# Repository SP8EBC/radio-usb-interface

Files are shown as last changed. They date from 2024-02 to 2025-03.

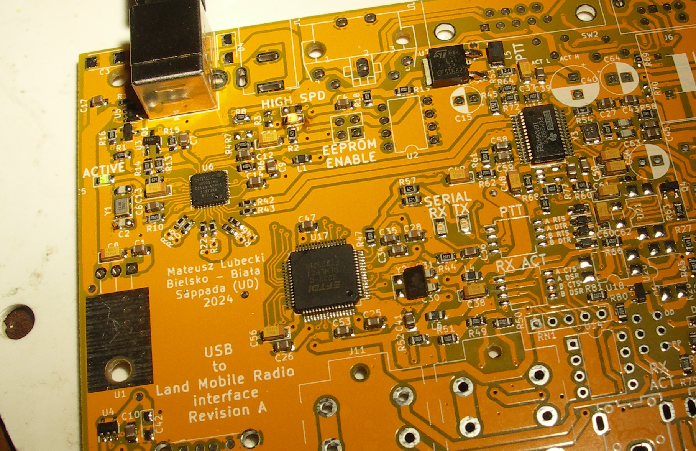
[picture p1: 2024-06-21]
_output_files/PICT0315.JPG

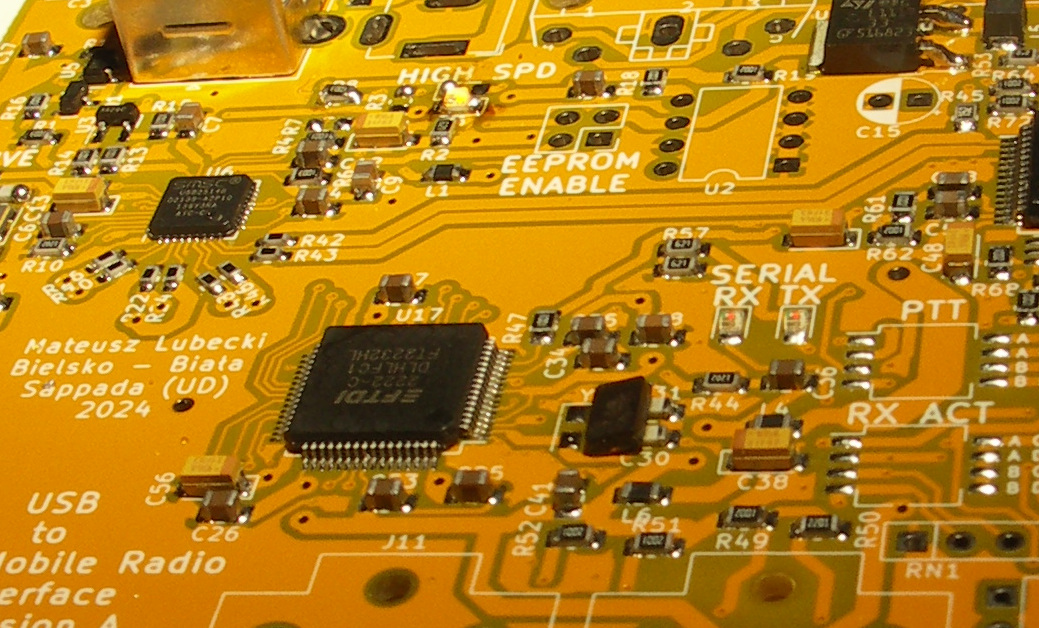
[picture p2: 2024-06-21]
_output_files/PICT0316.JPG

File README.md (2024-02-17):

# An USB interface between PC/RPi/ThinClient and any Land Mobile 2way Radio
Features:
1. Single USB connection to the PC.
2. Integrated USB 2.0 hub.
3. Integrated USB audio codec IC (Texas Instruments PCM2900) detected as a regular sound card.
4. Integrated double USB-UART controller (ftdi FT2232H) to control PTT and CarrierSense/COR/ChannelBusy lines.
5. Ground Separated RS232 for communication with the radio using CAT/IV-C or simmilar protocol
6. Ground Separated audio lines
7. Spare 2 USB ports exposed from the hub for connecting external devices.

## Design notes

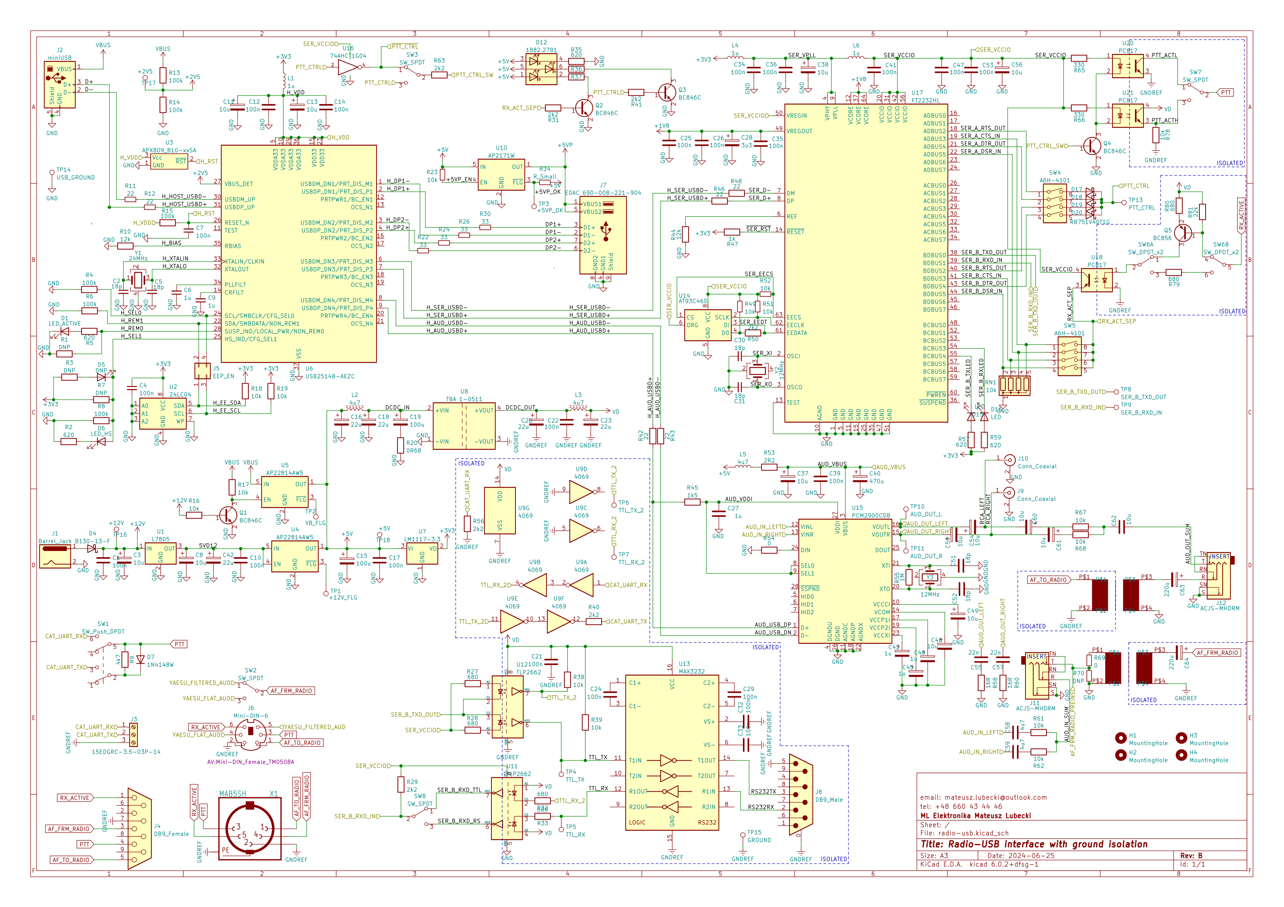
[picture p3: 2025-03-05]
__schematic/radio-usb.jpg

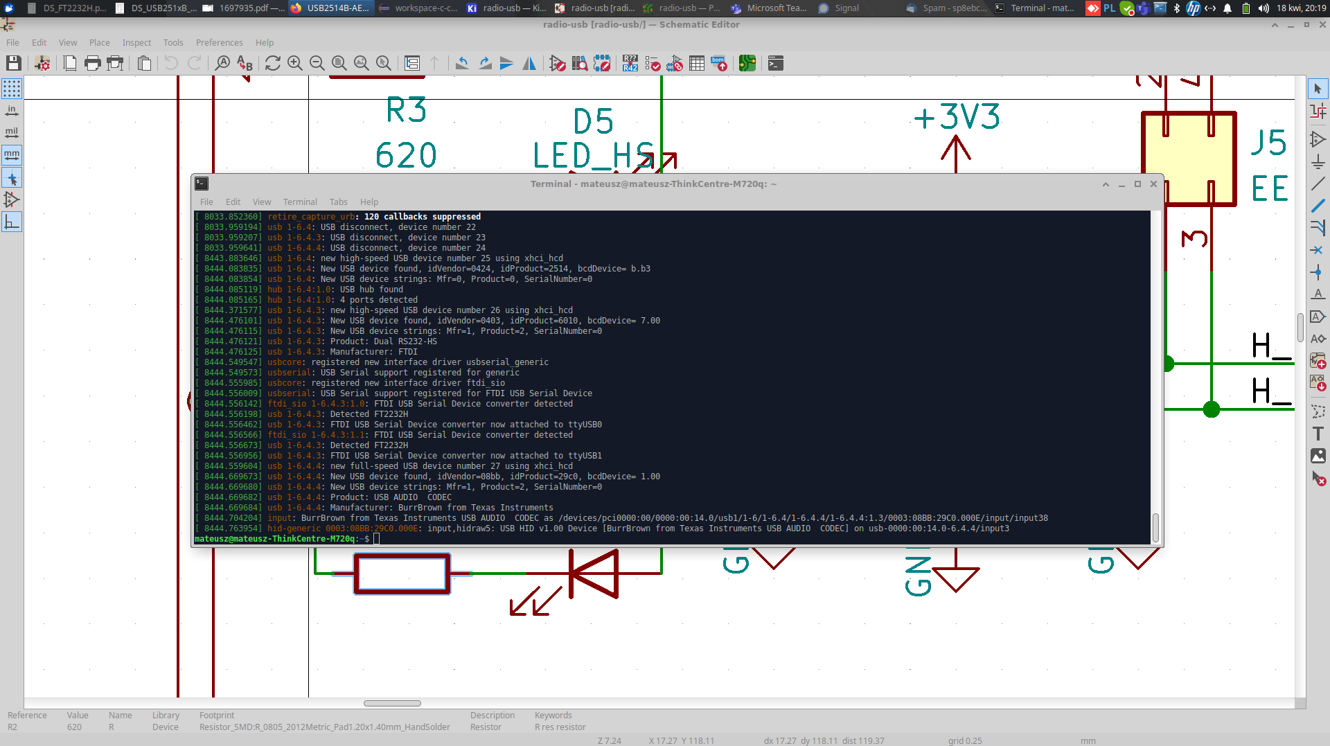
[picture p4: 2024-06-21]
_output_files/Screenshot_2024-04-18_20-19-46.png

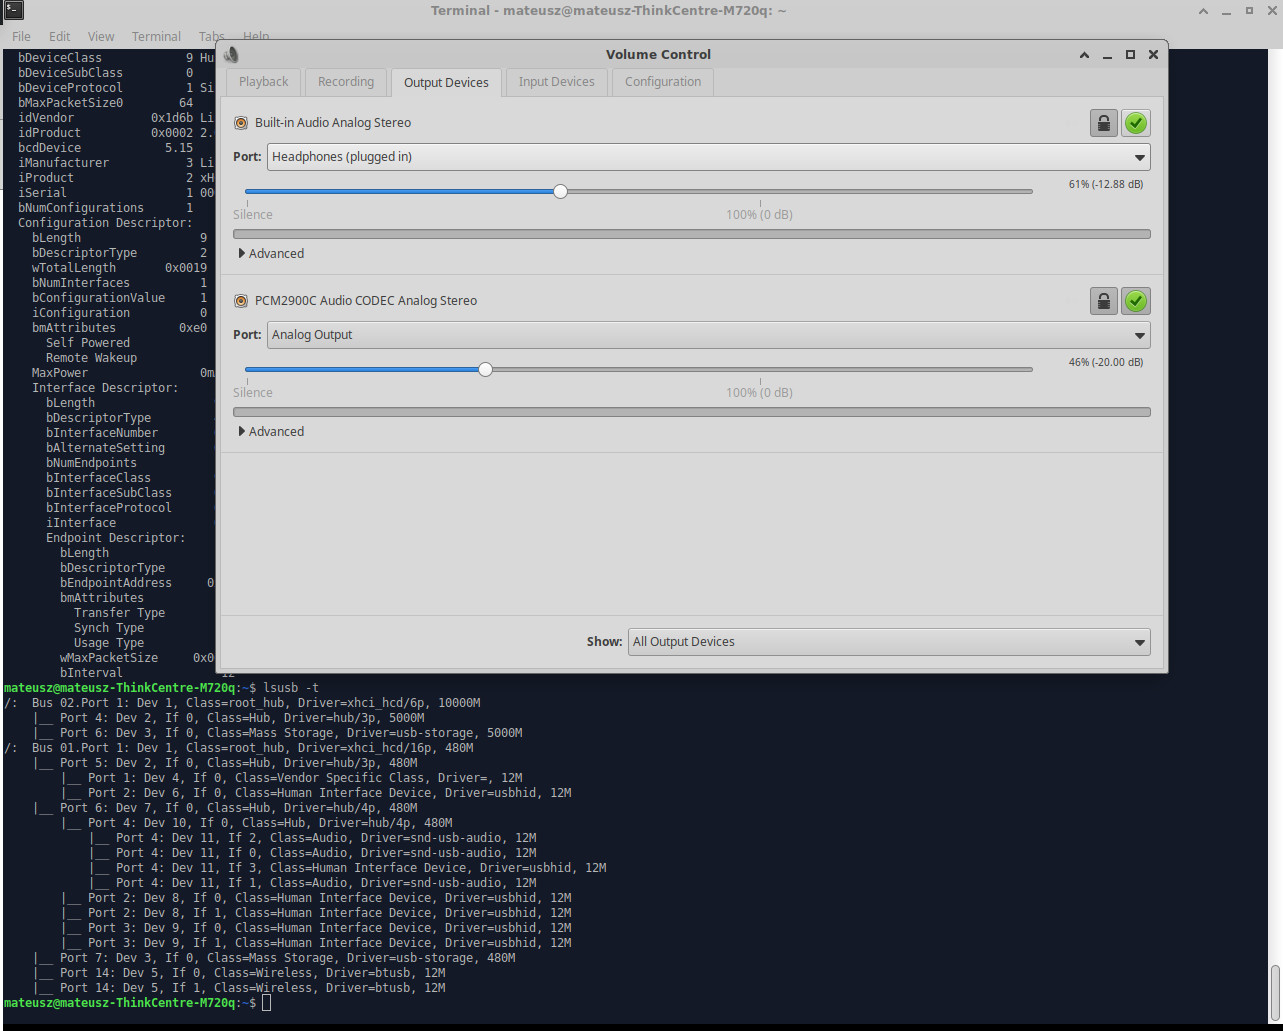
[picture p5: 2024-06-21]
_output_files/Screenshot_2024-04-16_18-32-28.jpg

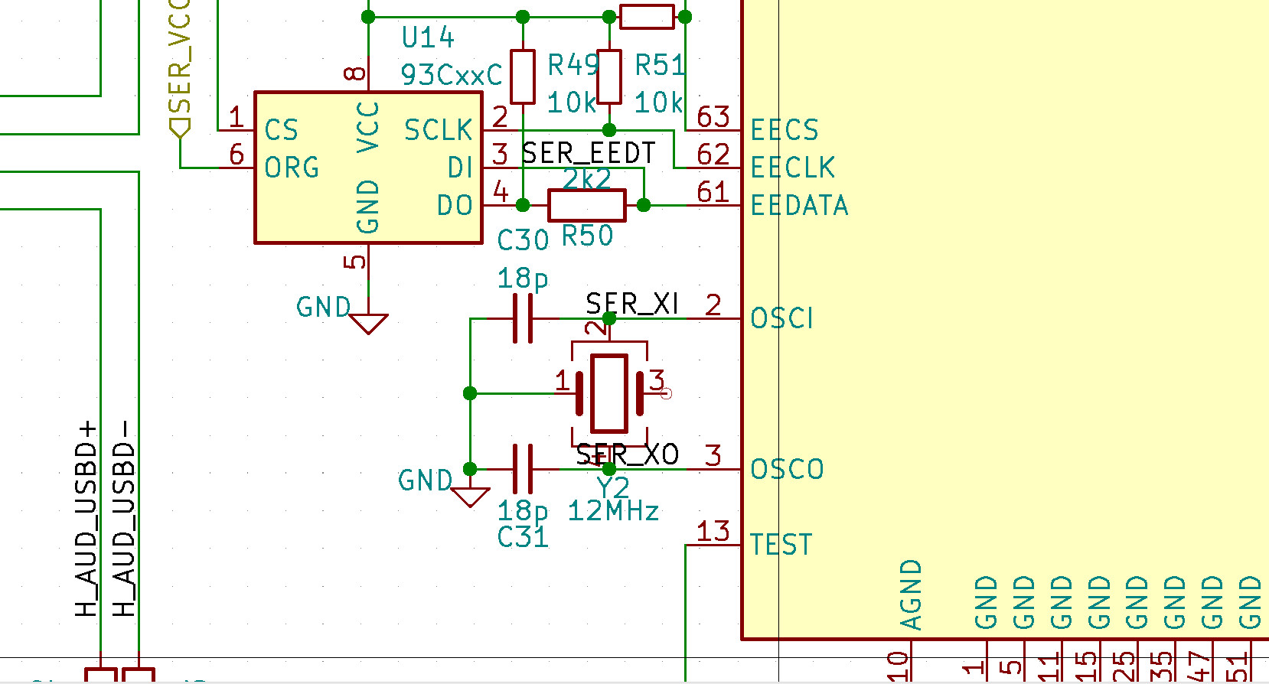
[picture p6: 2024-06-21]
_output_files/Screenshot_2024-04-16_21-14-47.jpg

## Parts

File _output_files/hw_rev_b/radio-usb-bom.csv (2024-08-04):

Reference | Quantity | Value | Footprint | Datasheet | DESCRIPTION
C1 C4 C7 C10 C12 C14 C17 C21 C22 C25 C26 C34 C35 C36 C39 C41 C47 C53 | 18 | 100n | Capacitor_SMD:C_0805_2012Metric_Pad1.18x1.45mm_HandSolder |  | 08051C104KAT2A KYOCERA AVX
C15 | 1 | 100u | Capacitor_THT:CP_Radial_D5.0mm_P2.50mm | https://www.tme.eu/Document/4bbe885c35326128adf3c0aebd83337c/e-bt.pdf | UBT1H101MPD8 NICHICON
C16 C18 C20 C23 C42 | 5 | 22u | Capacitor_Tantalum_SMD:CP_EIA-3216-18_Kemet-A_Pad1.58x1.35mm_HandSolder |  | TPSA106K010R0900 KYOCERA AVX
C19 | 1 | 100u | Capacitor_Tantalum_SMD:CP_EIA-3528-21_Kemet-B_Pad1.50x2.35mm_HandSolder |  | TPSA106K010R0900 KYOCERA AVX
C2 C5 C30 C31 C51 C52 | 6 | 18p | Capacitor_SMD:C_0805_2012Metric_Pad1.18x1.45mm_HandSolder |  | 08055A180JAT2A KYOCERA AVX
C24 C29 C32 C33 | 4 | 100n | Capacitor_SMD:C_0603_1608Metric_Pad1.08x0.95mm_HandSolder |  | 06033G104ZAT2A KYOCERA AVX
C28 | 1 | 3u3 | Capacitor_SMD:C_0805_2012Metric_Pad1.18x1.45mm_HandSolder |  | 0805ZD335KAT2A KYOCERA AVX
C3 | 1 | 10u | Capacitor_Tantalum_SMD:CP_EIA-6032-28_Kemet-C_Pad2.25x2.35mm_HandSolder |  | TPSA106K010R0900 KYOCERA AVX
C40 | 1 | 470u | Capacitor_THT:CP_Radial_D8.0mm_P3.50mm |  | NICHICON UHE1A471MPD1TA
C55 C57 | 2 | 22n | Capacitor_SMD:C_0805_2012Metric_Pad1.18x1.45mm_HandSolder |  | 08051C223KAT2A KYOCERA AVX
C58 C59 | 2 | 4u7 | Capacitor_SMD:C_0805_2012Metric_Pad1.18x1.45mm_HandSolder |  | 0805YC475KAT2A KYOCERA AVX
C6 C9 C27 C43 C45 C46 | 6 | 1u | Capacitor_SMD:C_0805_2012Metric_Pad1.18x1.45mm_HandSolder |  | 0805YC105KAT2A KYOCERA AVX
C62 | 1 | 10u | Capacitor_SMD:C_1206_3216Metric_Pad1.33x1.80mm_HandSolder |  | CL31A106MAHNNNE SAMSUNG
C63 C64 | 2 | 220u | Capacitor_THT:CP_Radial_D6.3mm_P2.50mm | https://www.tme.eu/Document/4bbe885c35326128adf3c0aebd83337c/e-bt.pdf | EEUFR1C221 PANASONIC
C8 C11 C13 C37 C38 C48 C49 C50 C54 C56 C60 C61 | 12 | 10u | Capacitor_Tantalum_SMD:CP_EIA-3216-18_Kemet-A_Pad1.58x1.35mm_HandSolder |  | TPSA106K010R0900 KYOCERA AVX
D1 | 1 | LED_ACTIVE | LED_SMD:LED_0805_2012Metric_Pad1.15x1.40mm_HandSolder |  | KPT-2012CGCK KINGBRIGHT ELECTRONIC
D12 | 1 | 1882.2781 | LED:LED_MENTOR_1882 | https://www.cree.com/led-components/media/documents/1397-QLS6BFKW.pdf | 1882.2781 MENTOR
D15 D16 | 2 | LED | LED_SMD:LED_0805_2012Metric_Pad1.15x1.40mm_HandSolder |  | KP-2012SYCK KINGBRIGHT ELECTRONIC
D17 D18 D19 D20 | 4 | RB751V40T1G | Diode_SMD:D_SOD-323_HandSoldering | https://www.tme.eu/Document/b77eb958f5d9ac56ef472a800d34775b/RB751V40T1.PDF | RB751V40T1G ONSEMI
D4 | 1 | B130-13-F | Diode_SMD:D_SMA |  | B130-13-F DIODES INCORPORATED
D5 D6 | 2 | LED_HS | LED_SMD:LED_0805_2012Metric_Pad1.15x1.40mm_HandSolder |  | KPT-2012SURC KINGBRIGHT ELECTRONIC
D7 | 1 | 1N4148W | Diode_SMD:D_SOD-123 | https://www.vishay.com/docs/85748/1n4148w.pdf | 1N4148W-AQ DIOTEC SEMICONDUCTOR
H1 H2 H3 H4 | 4 | MountingHole | MountingHole:MountingHole_3.2mm_M3
J1 | 1 | Barrel_Jack | Connector_BarrelJack:BarrelJack_GCT_DCJ200-10-A_Horizontal
J11 J12 | 2 | ACJS-MHDRM | AV:Jack_6.35mm_ACJS-MHDRM |  | ACJS-MHDRM AMPHENOL
J2 | 1 | miniUSB | Connector_USB:USB_B_Lumberg_2411_02_Horizontal | ~ | DS1099-WN0 CONNFLY
J3 | 1 | 15EDGRC-3.5-03P-14 | Connector_Phoenix_MC:PhoenixContact_MC_1,5_3-G-3.5_1x03_P3.50mm_Horizontal | https://www.tme.eu/Document/c7e2facf434c6541c93efde757aaf5e6/607.pdf
J4 | 1 | DB9_Female | Connector_Dsub:DSUB-9_Female_Horizontal_P2.77x2.84mm_EdgePinOffset4.94mm_Housed_MountingHolesOffset7.48mm | ~ | DE09-SN-24 ADAM TECH
J5 | 1 | EEP_EN | Connector_PinHeader_2.54mm:PinHeader_2x02_P2.54mm_Vertical
J6 | 1 | Mini-DIN-6 | AV:Mini-DIN_Female_TM0508A | http://service.powerdynamics.com/ec/Catalog17/Section%2011.pdf | 4850.2610 SCHURTER
J7 | 1 | EDAC 690-008-221-904 | Connector_USB:USB_A_Wuerth_61400826021_Horizontal_Stacked | https://www.tme.eu/Document/bc38f05e107515c145d033d39722883f/690-008-221-904.pdf | EDAC 690-008-221-904
J8 | 1 | DB9_Male | Connector_Dsub:DSUB-9_Male_Horizontal_P2.77x2.84mm_EdgePinOffset4.94mm_Housed_MountingHolesOffset7.48mm | ~ | DE09-PN-24 ADAM TECH
J9 J10 | 2 | Conn_Coaxial | AV:rca_cliff_F68371 | ~
L1 L4 L6 | 3 | 1u | Inductor_SMD:L_0805_2012Metric_Pad1.15x1.40mm_HandSolder |  | Viking NL05KTC1R0
L2 L3 L5 | 3 | 4u7 | Inductor_SMD:L_1210_3225Metric_Pad1.42x2.65mm_HandSolder | https://www.tme.eu/Document/11b7ed33a7ee93321756e8b8c8bd2191/VIKING-NLV.pdf | Viking NLV10MTC4R7
Q1 Q2 Q3 Q4 | 4 | BC846C | Package_TO_SOT_SMD:SOT-23 | https://assets.nexperia.com/documents/data-sheet/BC846_SER.pdf | BC846C-AQ DIOTEC SEMICONDUCTOR
Q5 | 1 | BC856 | Package_TO_SOT_SMD:SOT-23 | https://www.onsemi.com/pub/Collateral/BC860-D.pdf | BC856B-AQ DIOTEC SEMICONDUCTOR
R1 R4 R6 R8 R13 R14 R15 | 7 | 100k | Resistor_SMD:R_0805_2012Metric_Pad1.20x1.40mm_HandSolder |  | ERJ6ENF1002V PANASONIC
R10 R44 | 2 | 12k | Resistor_SMD:R_0805_2012Metric_Pad1.20x1.40mm_HandSolder |  | ERJ6ENF1202V PANASONIC
R11 R12 R42 R43 R46 R48 | 6 | 22 | Resistor_SMD:R_0603_1608Metric_Pad0.98x0.95mm_HandSolder |  | ERJ3EKF22R0V PANASONIC
R17 R78 | 2 | 10k | Resistor_SMD:R_0603_1608Metric_Pad0.98x0.95mm_HandSolder |  | ERJ3EKF1002V PANASONIC
R2 R3 R5 R57 R59 | 5 | 620 | Resistor_SMD:R_0805_2012Metric_Pad1.20x1.40mm_HandSolder |  | ERJ6GEYJ621V PANASONIC
R20 | 1 | 0R68 | Resistor_SMD:R_1206_3216Metric_Pad1.30x1.75mm_HandSolder
R22 R24 R26 R30 | 4 | 33 | Resistor_SMD:R_0603_1608Metric_Pad0.98x0.95mm_HandSolder |  | ERJ3EKF33R0V PANASONIC
R27 R28 R32 R33 R79 R80 | 6 | 680 | Resistor_SMD:R_0805_2012Metric_Pad1.20x1.40mm_HandSolder |  | ERA6AEB681V PANASONIC
R29 R31 R40 R41 R50 R56 R63 | 7 | 2k2 | Resistor_SMD:R_0805_2012Metric_Pad1.20x1.40mm_HandSolder |  | ERJ6ENF2201V PANASONIC
R34 | 1 | R_Small | Resistor_SMD:R_0805_2012Metric_Pad1.20x1.40mm_HandSolder
R35 R36 R37 | 3 | 620 | Resistor_SMD:R_0603_1608Metric_Pad0.98x0.95mm_HandSolder |  | ERJ3EKF6200V PANASONIC
R45 | 1 | 1k5 | Resistor_SMD:R_0805_2012Metric_Pad1.20x1.40mm_HandSolder |  | ERA6AEB152V PANASONIC
R47 | 1 | 1k | Resistor_SMD:R_0805_2012Metric_Pad1.20x1.40mm_HandSolder |  | ERJ6ENF1001V PANASONIC
R53 | 1 | 2R2 | Resistor_SMD:R_0805_2012Metric_Pad1.20x1.40mm_HandSolder |  | ERJP06J2R2V PANASONIC
R54 | 1 | 0 | Resistor_SMD:R_0805_2012Metric_Pad1.20x1.40mm_HandSolder |  | ERJ6GEY0R00V PANASONIC
R55 | 1 | 1M | Resistor_SMD:R_0805_2012Metric_Pad1.20x1.40mm_HandSolder |  | ERJ6ENF1004V PANASONIC
R58 R60 | 2 | 16R | Resistor_SMD:R_0805_2012Metric_Pad1.20x1.40mm_HandSolder |  | 0805S8F160JT5E ROYAL OHM
R65 R66 | 2 | 330 | Resistor_SMD:R_0805_2012Metric_Pad1.20x1.40mm_HandSolder |  | ERJ6ENF3300V PANASONIC
R69 | 1 | 0 | Resistor_SMD:R_0603_1608Metric_Pad0.98x0.95mm_HandSolder |  | ERJ3GEY0R00V PANASONIC
R7 R16 R18 R19 R23 R38 R39 R49 R51 R52 R61 R62 R67 R68 | 14 | 10k | Resistor_SMD:R_0805_2012Metric_Pad1.20x1.40mm_HandSolder |  | ERJ6ENF1002V PANASONIC
R70 | 1 | DNP | Resistor_SMD:R_0603_1608Metric_Pad0.98x0.95mm_HandSolder
R81 | 1 | 22k | Resistor_SMD:R_0805_2012Metric_Pad1.20x1.40mm_HandSolder |  | ERJ6ENF2202V PANASONIC
R9 | 1 | 4k7 | Resistor_SMD:R_0805_2012Metric_Pad1.20x1.40mm_HandSolder |  | ERJ6ENF4701V PANASONIC
RN1 | 1 | 10k | Resistor_THT:R_Array_SIP5 | http://www.vishay.com/docs/31509/csc.pdf | RNLA05G0103B0E ROYAL OHM
SW1 | 1 | SW_Push_DPDT | switches_spdt_dpdt:Alps_SSSS222700 | https://www.tme.eu/Document/c62ad11cd91cb94020bc0a3c66211e45/SSSS222700.PDF | Alps SSSS222700
SW2 SW7 | 2 | SW_SPDT | switches_spdt_dpdt:Alps_SSSS213000 | https://www.tme.eu/Document/2a8ee3f094bc2d9567cff99b6818da87/SSSS213000.PDF | SSSS213000 ALPS
SW3 | 1 | SW_SPDT | switches_spdt_dpdt:TL3XWO
SW4 SW5 | 2 | A6H-4101 | Button_Switch_SMD:SW_DIP_SPSTx04_Slide_Copal_CHS-04B_W7.62mm_P1.27mm |  | OMRON A6H-4101
SW6 | 1 | SW_DPDT_x2 | switches_spdt_dpdt:Alps_SSSS222700 | https://www.tme.eu/Document/c62ad11cd91cb94020bc0a3c66211e45/SSSS222700.PDF | ALPS SSSS222700
SW8 | 1 | SW_SPDT | switches_spdt_dpdt:Ninigi_MSS-2235S | https://www.tme.eu/Document/2a8ee3f094bc2d9567cff99b6818da87/SSSS213000.PDF | SSSS213000 ALPS
TP1 | 1 | +12V_FLG | TestPoint:TestPoint_Pad_D1.0mm
TP10 | 1 | AUD_OUT_L | TestPoint:TestPoint_Pad_D2.0mm
TP11 | 1 | AUD_OUT_R | TestPoint:TestPoint_Pad_D2.0mm
TP13 | 1 | PTT_CTRL | TestPoint:TestPoint_Pad_D2.0mm
TP14 | 1 | USB_GROUND | TestPoint:TestPoint_Pad_D2.0mm
TP15 | 1 | GROUND | TestPoint:TestPoint_Pad_D2.0mm
TP16 | 1 | +12V | TestPoint:TestPoint_Pad_D2.0mm
TP17 | 1 | +2V5 | TestPoint:TestPoint_Pad_D2.0mm
TP18 | 1 | +5V | TestPoint:TestPoint_Pad_D2.0mm
TP2 | 1 | VB_FLG | TestPoint:TestPoint_Pad_D1.0mm
TP3 | 1 | +5VP_OK | TestPoint:TestPoint_Pad_D2.0mm
TP4 | 1 | TTL_TX | TestPoint:TestPoint_Pad_D1.0mm
TP5 | 1 | TTL_RX | TestPoint:TestPoint_Pad_D1.0mm
TP6 | 1 | TTL_TX_2 | TestPoint:TestPoint_Pad_D1.0mm
TP7 | 1 | TTL_RX_2 | TestPoint:TestPoint_Pad_D2.0mm
TP8 | 1 | SER_B_TXD_OUT | TestPoint:TestPoint_Pad_D2.0mm
TP9 | 1 | SER_B_RXD_IN | TestPoint:TestPoint_Pad_D1.0mm
U1 | 1 | L7805 | Package_TO_SOT_THT:TO-220-3_Horizontal_TabDown | http://www.st.com/content/ccc/resource/technical/document/datasheet/41/4f/b3/b0/12/d4/47/88/CD00000444.pdf/files/CD00000444.pdf/jcr:content/translations/en.CD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
U10 | 1 | AP2171W | Package_TO_SOT_SMD:SOT-23-5 | https://www.diodes.com/assets/Datasheets/AP2161.pdf | DIODES INCORPORATED AP2171WG-7
U13 | 1 | MAX3232 | Package_SO:TSSOP-16_4.4x5mm_P0.65mm | https://datasheets.maximintegrated.com/en/ds/MAX3222-MAX3241.pdf
U14 | 1 | AT93C46D | Package_DIP:DIP-8_W7.62mm | http://ww1.microchip.com/downloads/en/DeviceDoc/20001749K.pdf | 93C46A-I/P MICROCHIP TECHNOLOGY
U15 | 1 | PCM2900CDB | Package_SO:SSOP-28_5.3x10.2mm_P0.65mm | http://www.ti.com/lit/ds/symlink/pcm2902c.pdf | TEXAS INSTRUMENTS PCM2900CDB
U16 | 1 | 74AHCT1G04 | Package_TO_SOT_SMD:SOT-23-5_HandSoldering | http://www.ti.com/lit/sg/scyt129e/scyt129e.pdf
U17 | 1 | FT2232HL | Package_QFP:LQFP-64_10x10mm_P0.5mm | https://www.ftdichip.com/Support/Documents/DataSheets/ICs/DS_FT2232H.pdf | FTDI FT2232HL
U18 U20 U21 | 3 | PC817 | Package_DIP:SMDIP-4_W7.62mm | http://www.soselectronic.cz/a_info/resource/d/pc817.pdf
U19 U22 | 2 | CRIYCHLEY9000 | paratnc_cp:NORMAL
U2 | 1 | 24LC04 | Package_DIP:DIP-8_W7.62mm | http://ww1.microchip.com/downloads/en/DeviceDoc/21708K.pdf | 24LC04BH-I/P MICROCHIP TECHNOLOGY
U3 | 1 | APX809_810-xxSA | Package_TO_SOT_SMD:SOT-23_Handsoldering |  | APX809S-29SA-7 DIODES INCORPORATED
U4 U5 | 2 | AP22814AW5 | Package_TO_SOT_SMD:SOT-23-5 | https://www.diodes.com/assets/Datasheets/AP22804_14.pdf | DIODES INCORPORATED AP22814AW5-7
U6 | 1 | USB2514B-AEZC | Package_DFN_QFN:QFN-36-1EP_6x6mm_P0.5mm_EP3.7x3.7mm | http://ww1.microchip.com/downloads/en/DeviceDoc/00001692C.pdf | MICROCHIP TECHNOLOGY USB2514B-AEZC
U7 | 1 | LM1117-3.3 | Package_TO_SOT_SMD:TO-252-2 | http://www.ti.com/lit/ds/symlink/lm1117.pdf | LM1117DTX-3.3 TEXAS INSTRUMENTS
U8 | 1 | TBA 1-0511 | Converter_DCDC:Converter_DCDC_Murata_CRE1xxxxxx3C_THT | https://www.tme.eu/Document/04c8092078f15ad8e8fca758a461a5e9/tba1-datasheet.pdf | TBA 1-0511 TRACO POWER
U9 | 1 | 4069 | Package_SO:TSSOP-14_4.4x5mm_P0.65mm | http://www.intersil.com/content/dam/Intersil/documents/cd40/cd4069ubms.pdf
X1 | 1 | MAB5SH | sterownik-eagle:MAB5SH
Y1 | 1 | 24MHz | Crystal:Crystal_SMD_Abracon_ABM8G-4Pin_3.2x2.5mm |  | 24.00M-SMDXT324 YIC
Y2 Y3 | 2 | 12MHz | Crystal:Crystal_SMD_Abracon_ABM8G-4Pin_3.2x2.5mm |  | 7V-12.000MDDJ-T TXC

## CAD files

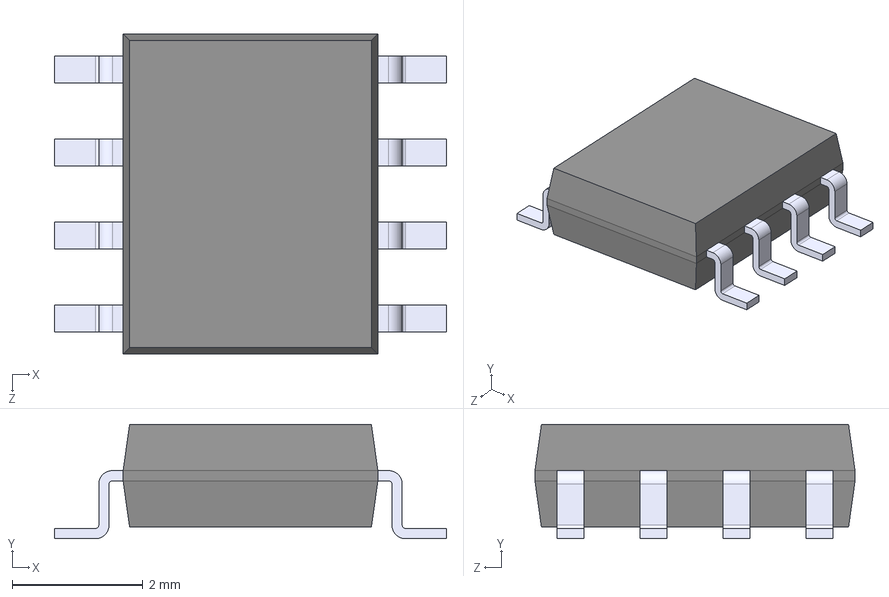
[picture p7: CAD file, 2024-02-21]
MIC5209-3.6YM/MIC5209-3.6YM.step
6.00 x 1.75 x 4.90 mm

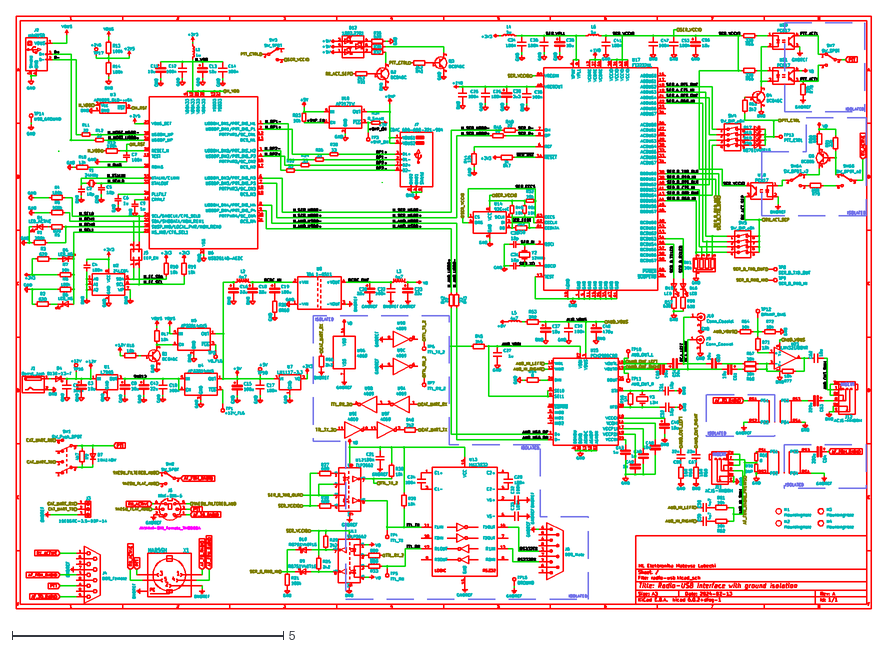
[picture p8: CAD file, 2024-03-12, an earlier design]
_output_files/hw_rev_a/___schematic/radio-usb.dxf
15.7 x 10.9

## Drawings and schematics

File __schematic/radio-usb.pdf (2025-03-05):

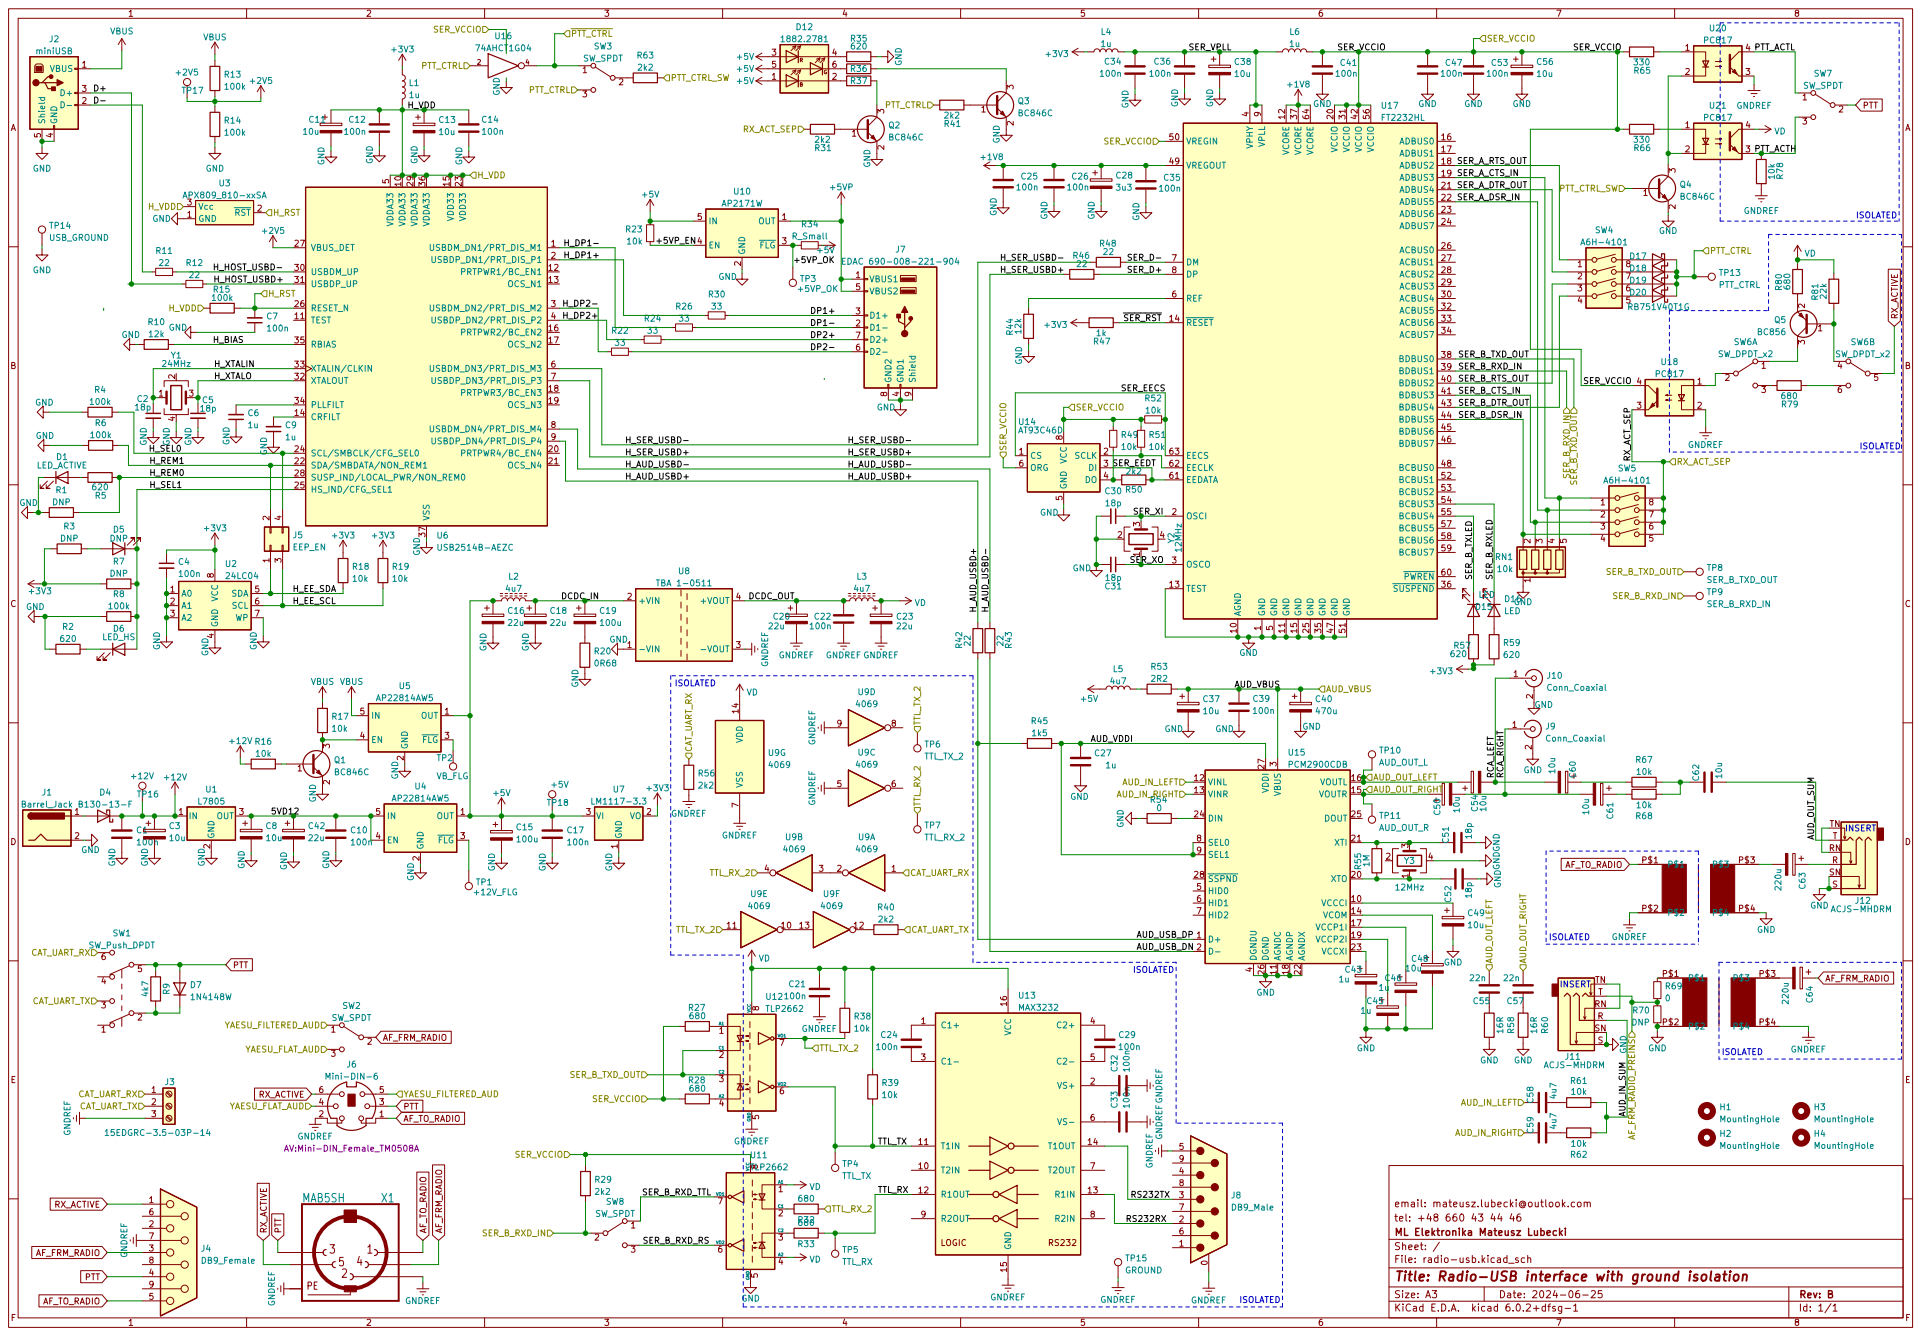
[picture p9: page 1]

1 AGND 10 GND 11 VCORE 12 TEST 13 ~{RESET} 14 GND 15 ADBUS0 16 ADBUS1 17 ADBUS2 18 ADBUS3 19 OSCI 2 VCCIO 20 ADBUS4 21 ADBUS5 22 ADBUS6 23 ADBUS7 24 GND 25 ACBUS0 26 ACBUS1 27 ACBUS2 28 ACBUS3 29 OSCO 3 ACBUS4 30 VCCIO 31 ACBUS5 32 ACBUS6 33 ACBUS7 34 GND 35

4 BDBUS2 40 BDBUS3 41 VCCIO 42 BDBUS4 43 BDBUS5 44 BDBUS6 45 BDBUS7 46 GND 47 BCBUS0 48 VREGOUT 49 GND

5 VREGIN 50 GND 51 BCBUS1 52 BCBUS2 53 BCBUS3 54 BCBUS4 55 VCCIO 56 BCBUS5 57 BCBUS6 58 BCBUS7 59 REF 6 ~{PWREN} 60 EEDATA 61 EECLK 62 EECS 63 VCORE 64 DM 7 DP 8 VPLL

4 SDA 5 SCL 6 WP 7 VCC

J6 Mini-DIN-6 AV:Mini-DIN_Female_TM0508A

email: mateusz.lubecki@outlook.com
tel: +48 660 43 44 46
File: radio-usb.kicad_sch Sheet: / ML Elektronika Mateusz Lubecki

Id: 1/1 Title: Radio-USB interface with ground isolation

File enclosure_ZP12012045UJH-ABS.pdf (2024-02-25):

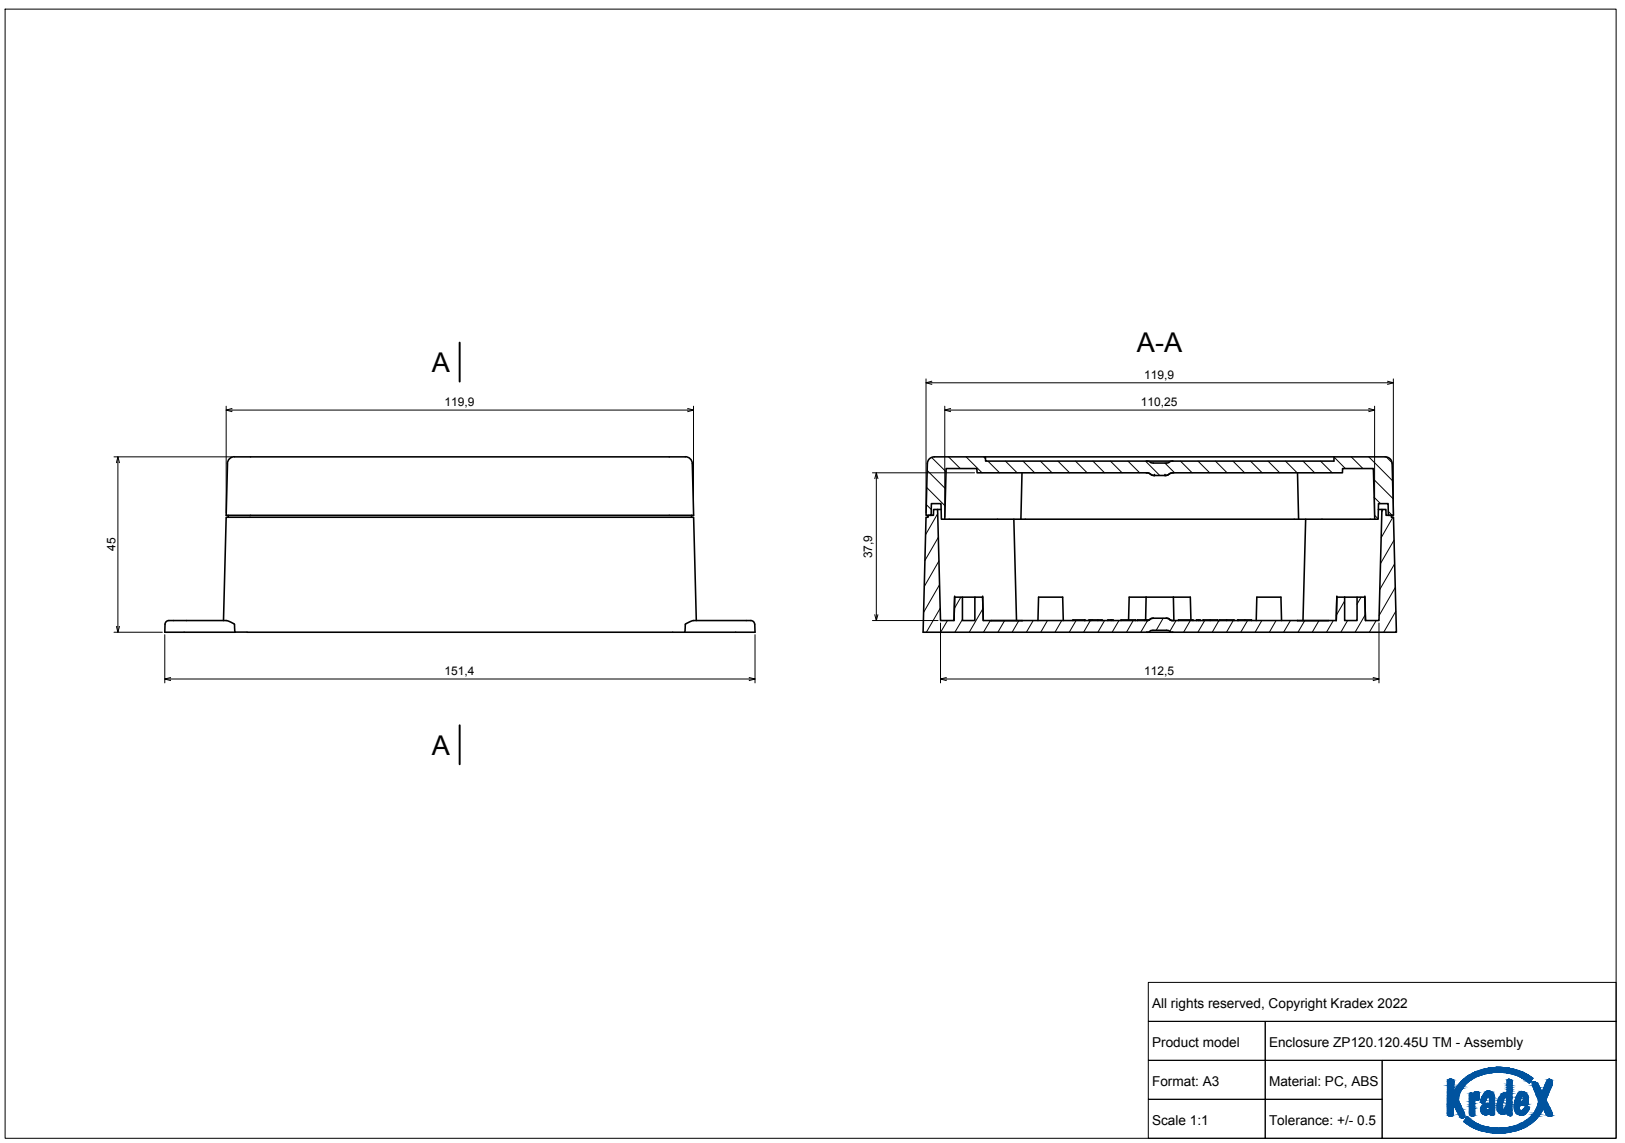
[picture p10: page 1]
Product model Format: A3 Scale 1:1; Tolerance: +/- 0.5 Material: PC, ABS Enclosure ZP120.120.45U TM - Assembly All rights reserved, Copyright Kradex 2022 AA

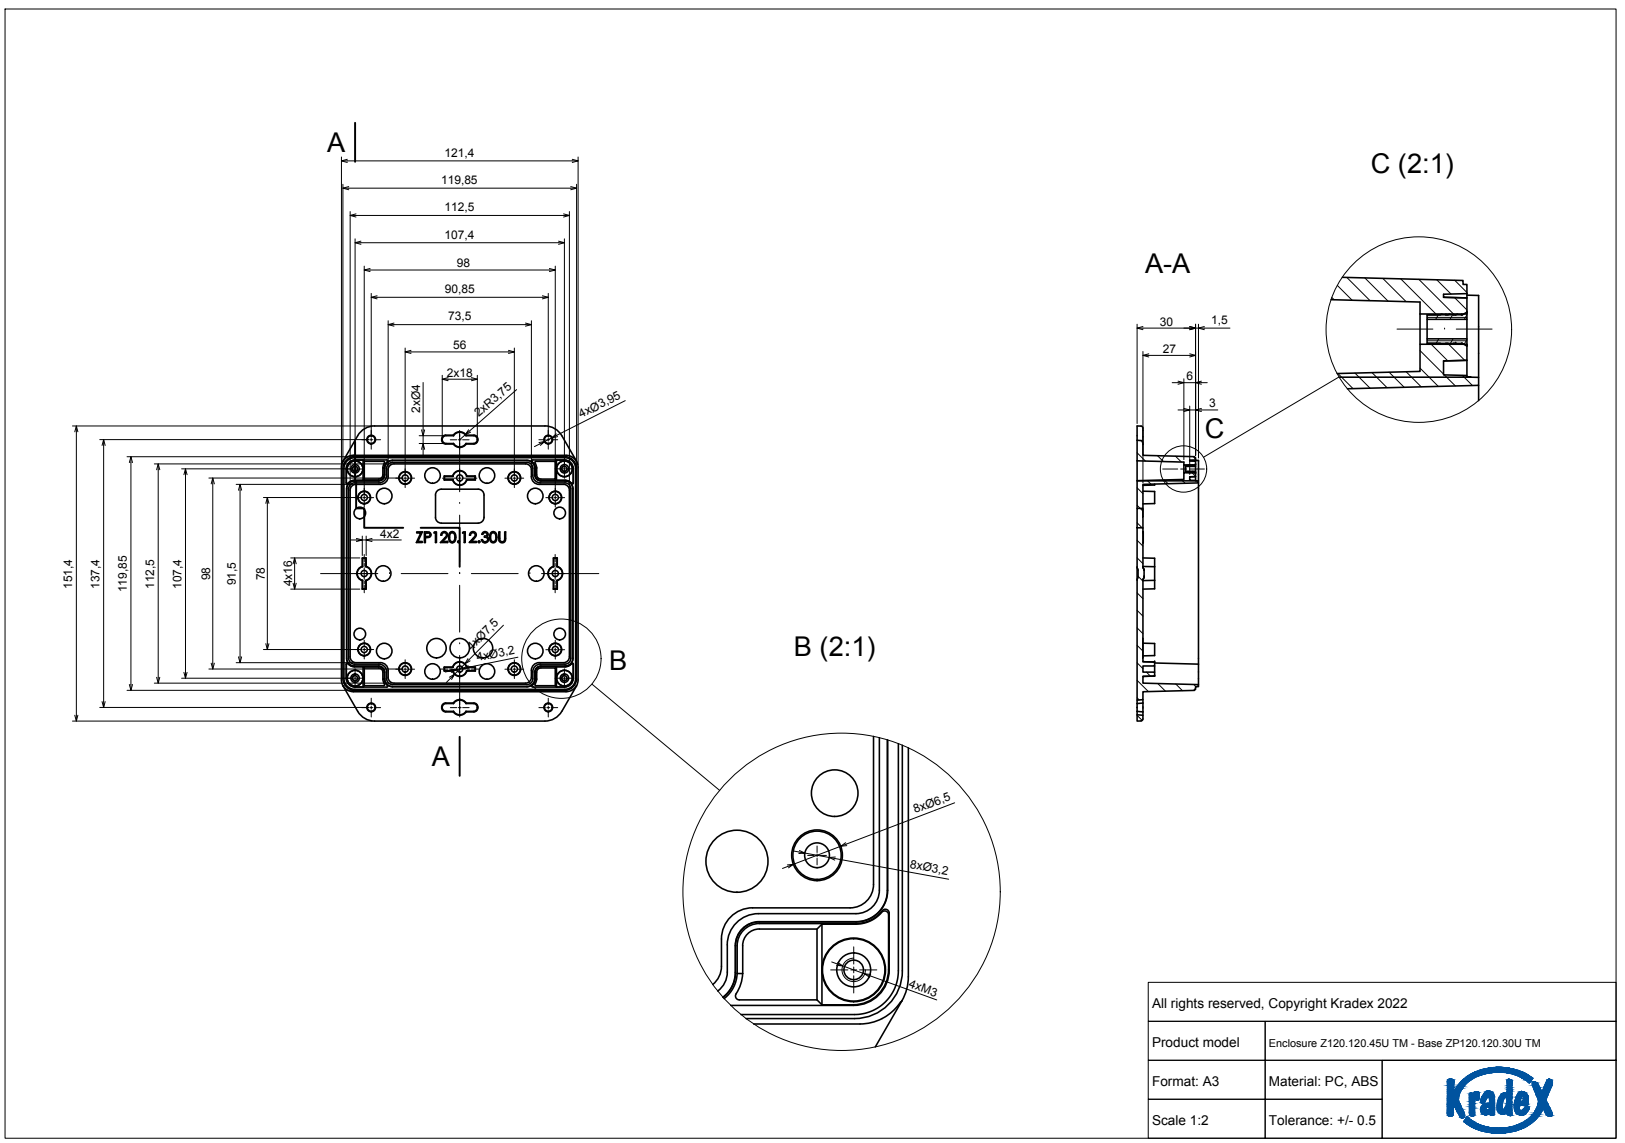
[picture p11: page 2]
Product model Format: A3 Scale 1:2; Tolerance: +/- 0.5 Material: PC, ABS Enclosure Z120.120.45U TM - Base ZP120.120.30U TM All rights reserved, Copyright Kradex 2022 A

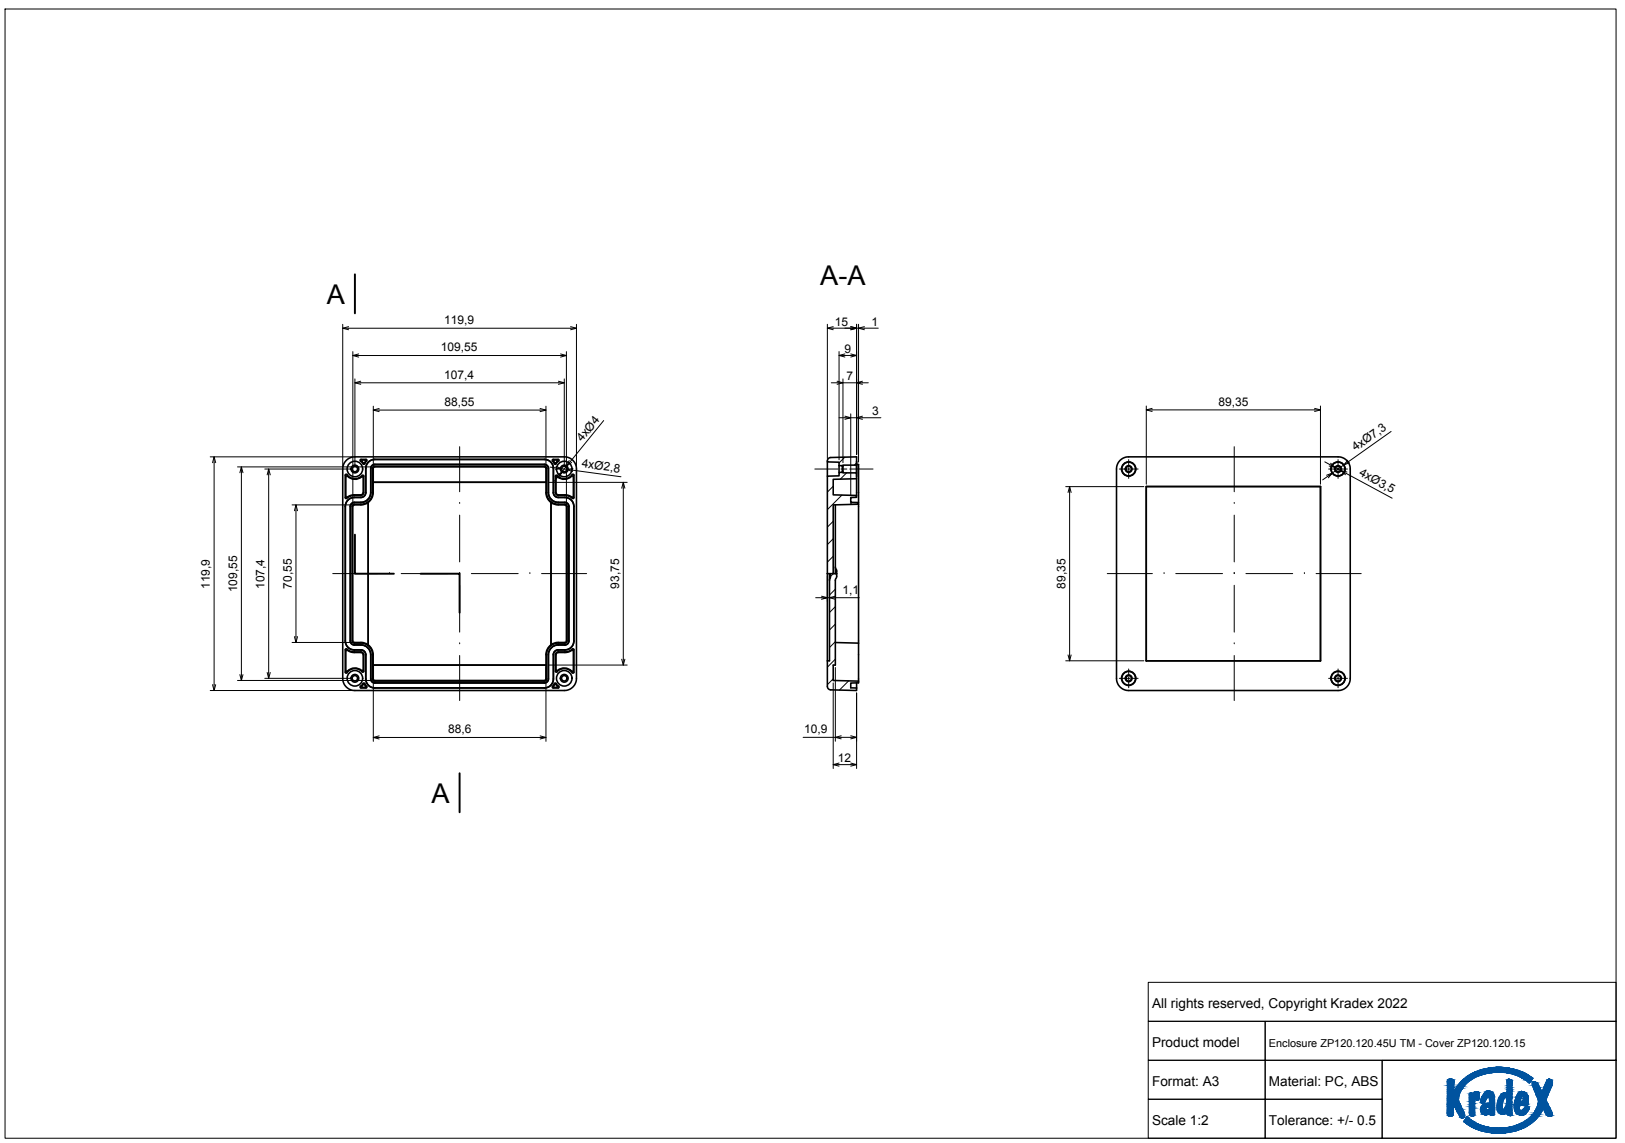
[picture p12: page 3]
Product model Format: A3 Scale 1:2; Tolerance: +/- 0.5 Material: PC, ABS Enclosure ZP120.120.45U TM - Cover ZP120.120.15 All rights reserved, Copyright Kradex 2022

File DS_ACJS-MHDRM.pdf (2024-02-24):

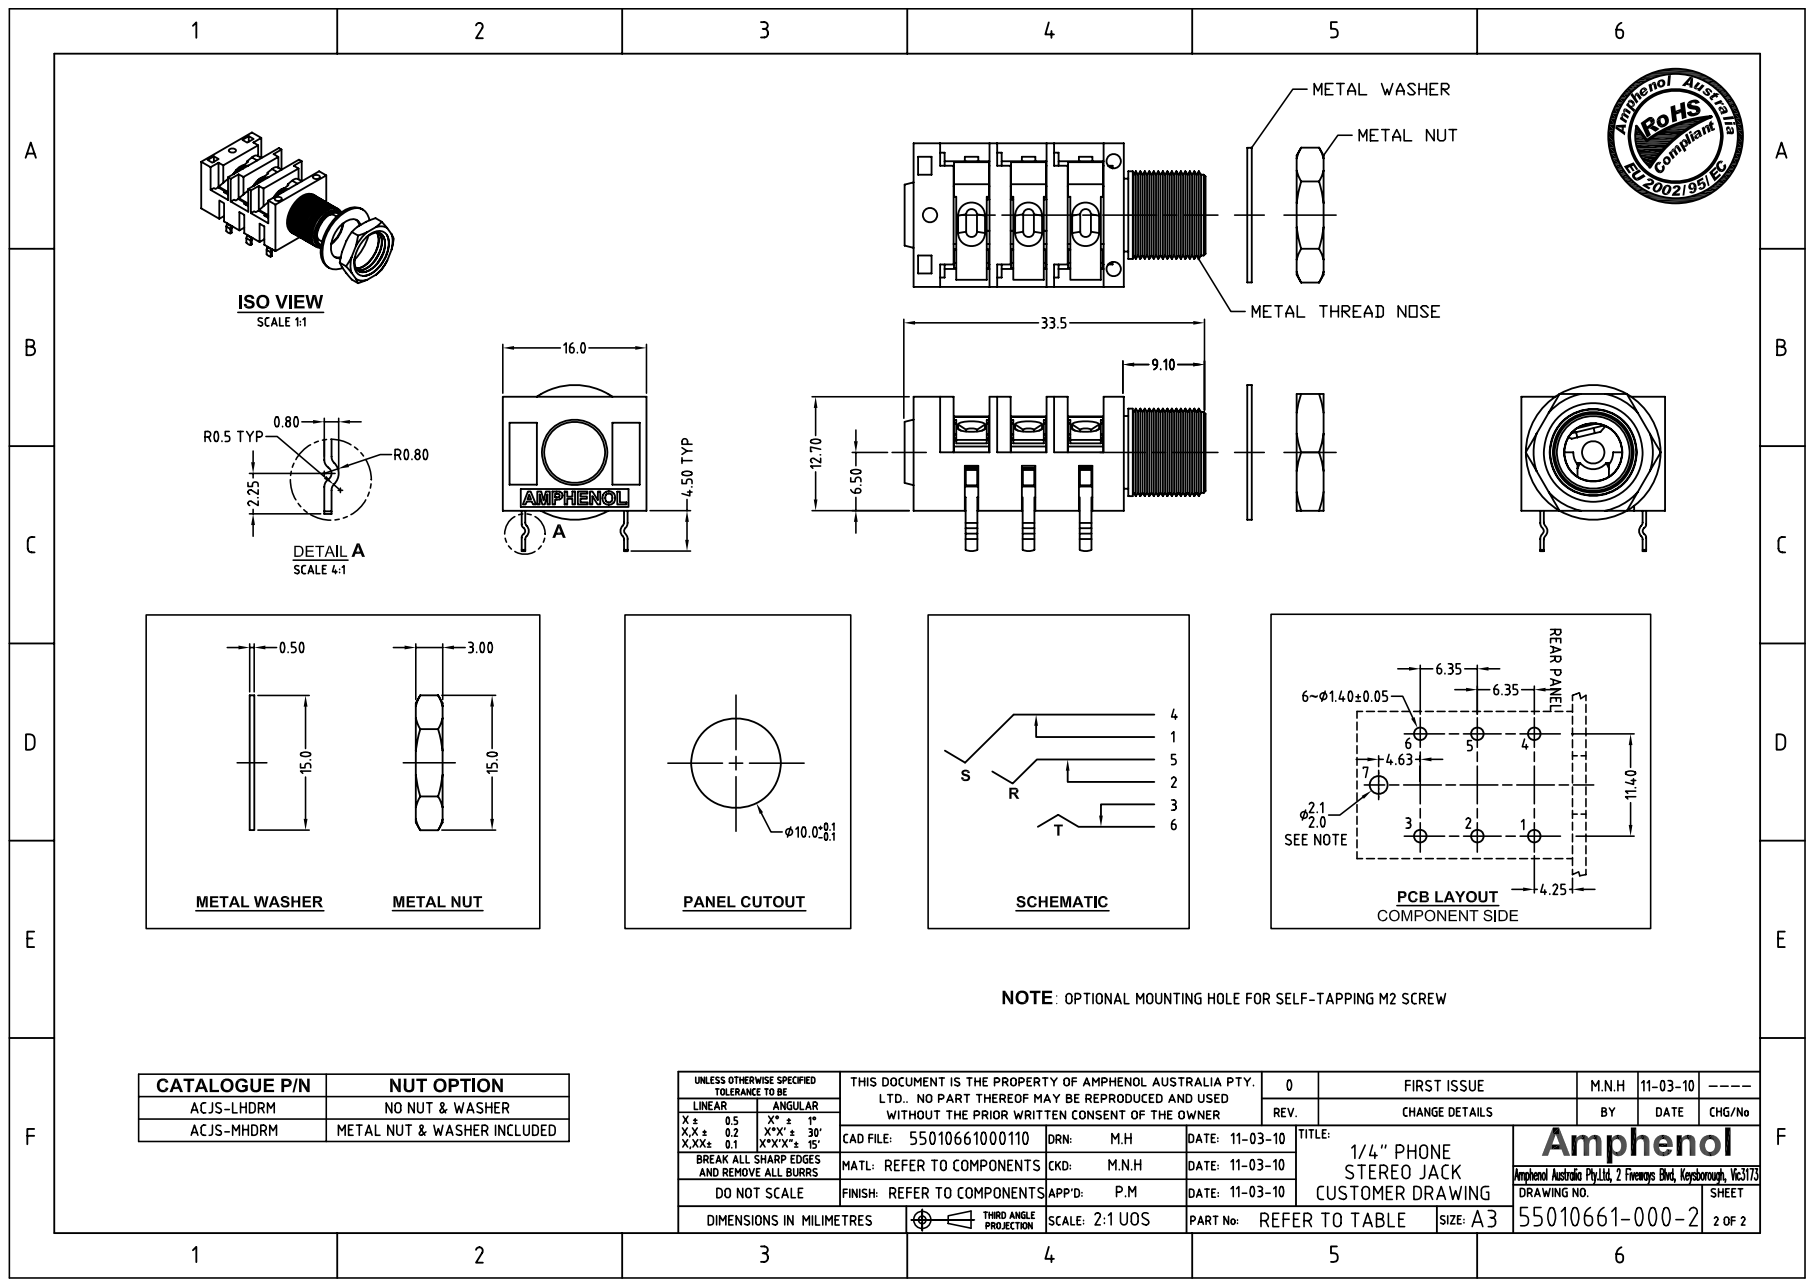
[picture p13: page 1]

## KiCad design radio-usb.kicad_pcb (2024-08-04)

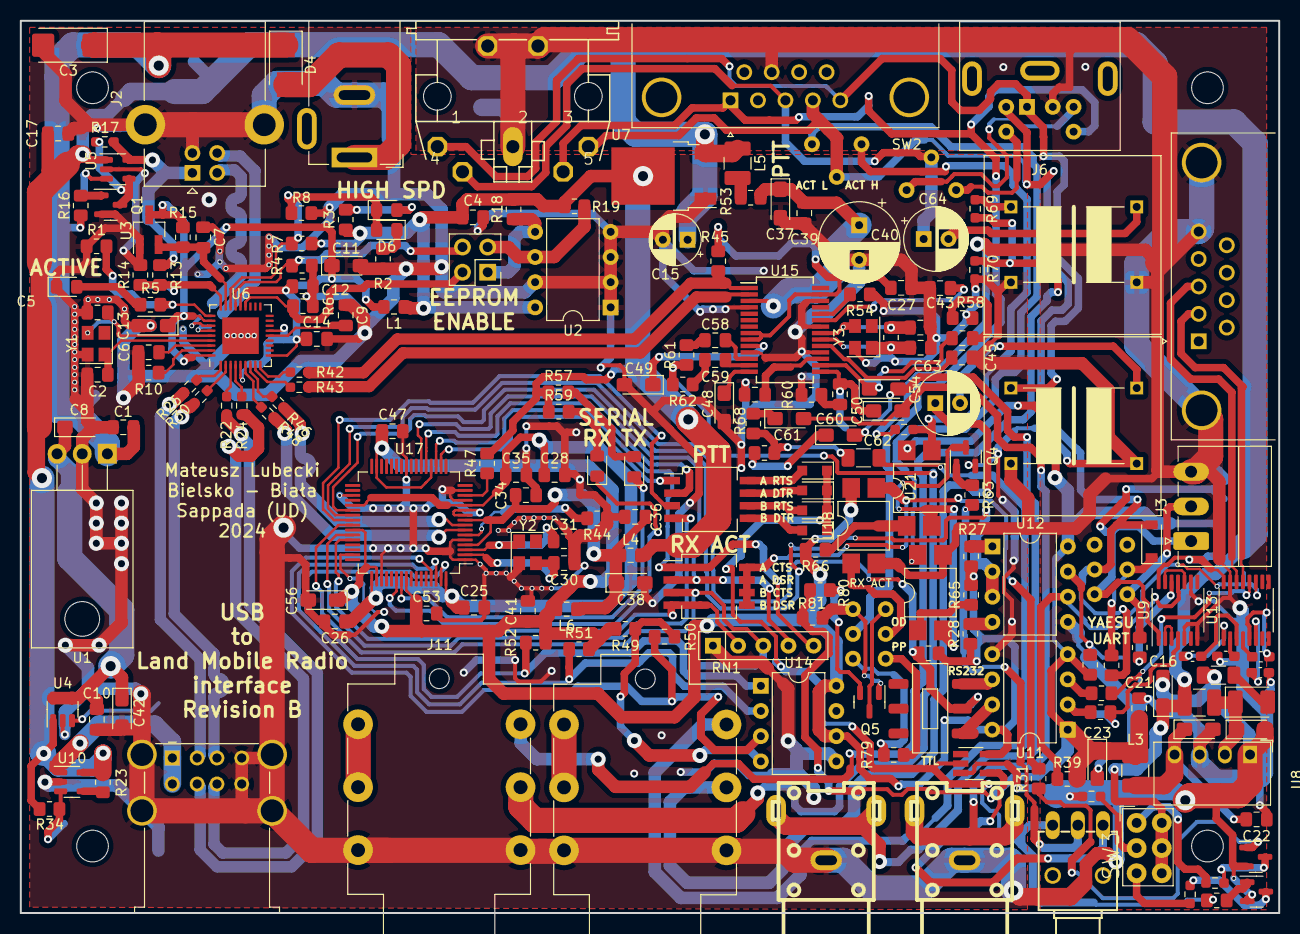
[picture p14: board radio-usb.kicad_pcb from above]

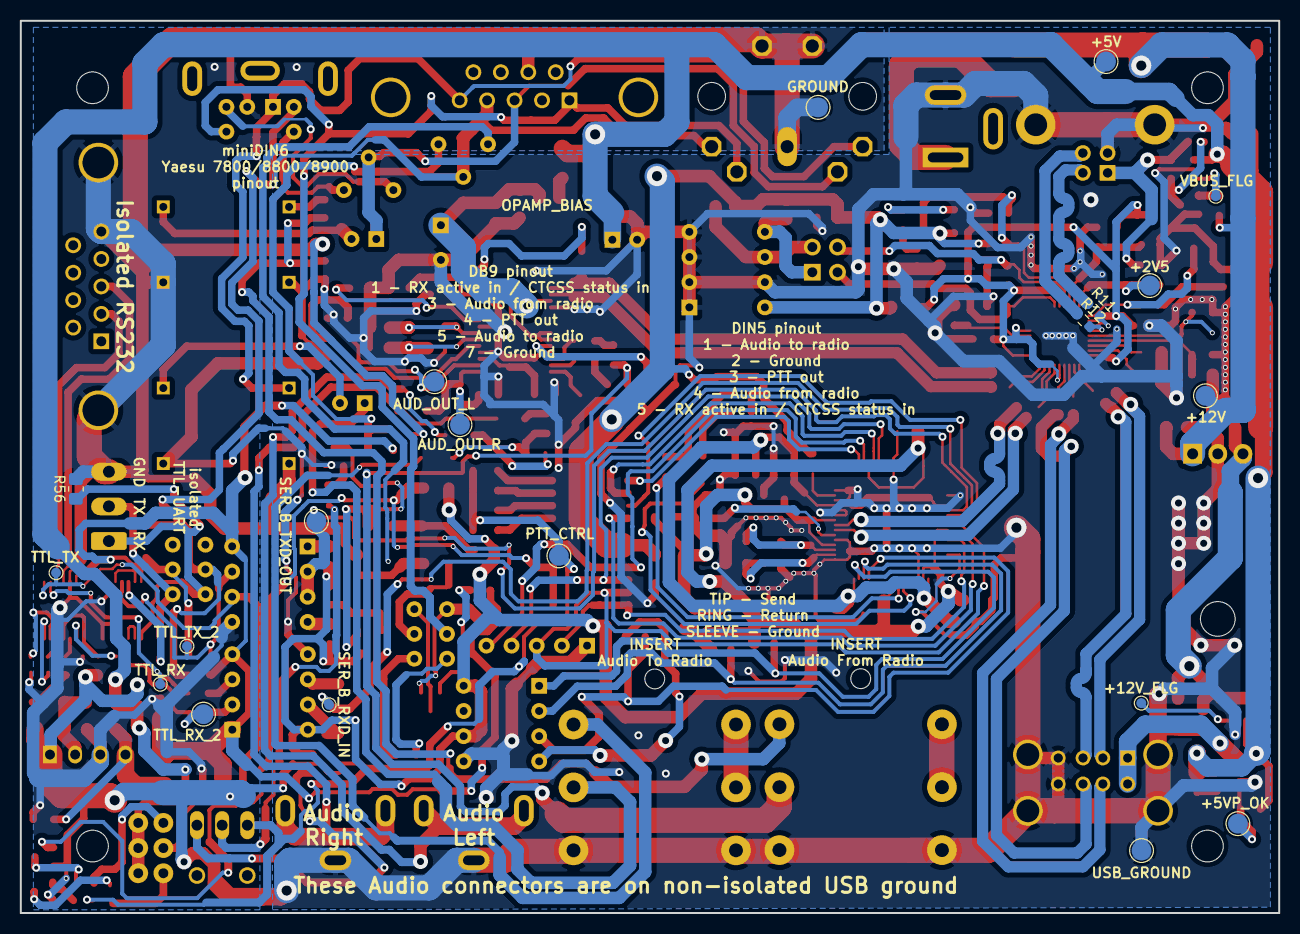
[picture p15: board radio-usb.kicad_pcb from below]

Board: 2 copper layers, 127.0 x 90.0 mm, 225 parts (20 on the bottom side), 171 nets.

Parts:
C1, C4, C7, C10, C12, C14, C17, C21, C22, C25, C26, C34, C35, C36, C39, C41, C47, C53: 100n; C_0805_2012Metric_Pad1.18x1.45mm_HandSolder
C2, C5, C30, C31, C51, C52: 18p; C_0805_2012Metric_Pad1.18x1.45mm_HandSolder
C3: 10u; CP_EIA-6032-28_Kemet-C_Pad2.25x2.35mm_HandSolder
C6, C9, C27, C43, C45, C46: 1u; C_0805_2012Metric_Pad1.18x1.45mm_HandSolder
C8, C11, C13, C37, C38, C48, C49, C50, C54, C56, C60, C61: 10u; CP_EIA-3216-18_Kemet-A_Pad1.58x1.35mm_HandSolder
C15: 100u; CP_Radial_D5.0mm_P2.50mm
C16, C18, C20, C23, C42: 22u; CP_EIA-3216-18_Kemet-A_Pad1.58x1.35mm_HandSolder
C19: 100u; CP_EIA-3528-21_Kemet-B_Pad1.50x2.35mm_HandSolder
C24, C29, C32, C33: 100n; C_0603_1608Metric_Pad1.08x0.95mm_HandSolder
C28: 3u3; C_0805_2012Metric_Pad1.18x1.45mm_HandSolder
C40: 470u; CP_Radial_D8.0mm_P3.50mm
C55, C57: 22n; C_0805_2012Metric_Pad1.18x1.45mm_HandSolder
C58, C59: 4u7; C_0805_2012Metric_Pad1.18x1.45mm_HandSolder
C62: 10u; C_1206_3216Metric_Pad1.33x1.80mm_HandSolder
C63, C64: 220u; CP_Radial_D6.3mm_P2.50mm
D1: LED_ACTIVE; LED_0805_2012Metric_Pad1.15x1.40mm_HandSolder
D4: B130-13-F; D_SMA
D5: DNP; LED_0805_2012Metric_Pad1.15x1.40mm_HandSolder
D6: LED_HS; LED_0805_2012Metric_Pad1.15x1.40mm_HandSolder
D7: 1N4148W; D_SOD-123
D12: 1882.2781; LED_MENTOR_1882
D15, D16: LED; LED_0805_2012Metric_Pad1.15x1.40mm_HandSolder
D17, D18, D19, D20: RB751V40T1G; D_SOD-323_HandSoldering
H1, H2, H3, H4: MountingHole; MountingHole_3.2mm_M3
J1: Barrel_Jack; BarrelJack_GCT_DCJ200-10-A_Horizontal
J2: miniUSB; USB_B_Lumberg_2411_02_Horizontal
J3: 15EDGRC-3.5-03P-14; PhoenixContact_MC_1,5_3-G-3.5_1x03_P3.50mm_Horizontal
J4: DB9_Female; DSUB-9_Female_Horizontal_P2.77x2.84mm_EdgePinOffset4.94mm_H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
J5: EEP_EN; PinHeader_2x02_P2.54mm_Vertical
J6: Mini-DIN-6; Mini-DIN_Female_TM0508A
J7: EDAC 690-008-221-904; USB_A_Wuerth_61400826021_Horizontal_Stacked
J8: DB9_Male; DSUB-9_Male_Horizontal_P2.77x2.84mm_EdgePinOffset4.94mm_Hou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
J9, J10: Conn_Coaxial; rca_cliff_F68371
J11, J12: ACJS-MHDRM; Jack_6.35mm_ACJS-MHDRM
L1, L4, L6: 1u; L_0805_2012Metric_Pad1.15x1.40mm_HandSolder
L2, L3, L5: 4u7; L_1210_3225Metric_Pad1.42x2.65mm_HandSolder
Q1, Q2, Q3, Q4: BC846C; SOT-23
Q5: BC856; SOT-23
R1, R3, R7: DNP; R_0805_2012Metric_Pad1.20x1.40mm_HandSolder
R2, R5, R57, R59: 620; R_0805_2012Metric_Pad1.20x1.40mm_HandSolder
R4, R6, R8, R13, R14, R15: 100k; R_0805_2012Metric_Pad1.20x1.40mm_HandSolder
R9: 4k7; R_0805_2012Metric_Pad1.20x1.40mm_HandSolder
R10, R44: 12k; R_0805_2012Metric_Pad1.20x1.40mm_HandSolder
R11, R12, R42, R43, R46, R48: 22; R_0603_1608Metric_Pad0.98x0.95mm_HandSolder
R16, R18, R19, R23, R38, R39, R49, R51, R52, R61, R62, R67, R68: 10k; R_0805_2012Metric_Pad1.20x1.40mm_HandSolder
R17, R78: 10k; R_0603_1608Metric_Pad0.98x0.95mm_HandSolder
R20: 0R68; R_1206_3216Metric_Pad1.30x1.75mm_HandSolder
R22, R24, R26, R30: 33; R_0603_1608Metric_Pad0.98x0.95mm_HandSolder
R27, R28, R32, R33, R79, R80: 680; R_0805_2012Metric_Pad1.20x1.40mm_HandSolder
R29, R31, R40, R41, R50, R56, R63: 2k2; R_0805_2012Metric_Pad1.20x1.40mm_HandSolder
R34: R_Small; R_0805_2012Metric_Pad1.20x1.40mm_HandSolder
R35, R36, R37: 620; R_0603_1608Metric_Pad0.98x0.95mm_HandSolder
R45: 1k5; R_0805_2012Metric_Pad1.20x1.40mm_HandSolder
R47: 1k; R_0805_2012Metric_Pad1.20x1.40mm_HandSolder
R53: 2R2; R_0805_2012Metric_Pad1.20x1.40mm_HandSolder
R54: 0; R_0805_2012Metric_Pad1.20x1.40mm_HandSolder
R55: 1M; R_0805_2012Metric_Pad1.20x1.40mm_HandSolder
R58, R60: 16R; R_0805_2012Metric_Pad1.20x1.40mm_HandSolder
R65, R66: 330; R_0805_2012Metric_Pad1.20x1.40mm_HandSolder
R69: 0; R_0603_1608Metric_Pad0.98x0.95mm_HandSolder
R70: DNP; R_0603_1608Metric_Pad0.98x0.95mm_HandSolder
R81: 22k; R_0805_2012Metric_Pad1.20x1.40mm_HandSolder
RN1: 10k; R_Array_SIP5
SW1: SW_Push_DPDT; Alps_SSSS222700
SW2, SW7: SW_SPDT; Alps_SSSS213000
SW3: SW_SPDT; TL3XWO
SW4, SW5: A6H-4101; SW_DIP_SPSTx04_Slide_Copal_CHS-04B_W7.62mm_P1.27mm
SW6: SW_DPDT_x2; Alps_SSSS222700
SW8: SW_SPDT; Ninigi_MSS-2235S
TP1: +12V_FLG; TestPoint_Pad_D1.0mm
TP2: VB_FLG; TestPoint_Pad_D1.0mm
TP3: +5VP_OK; TestPoint_Pad_D2.0mm
TP4: TTL_TX; TestPoint_Pad_D1.0mm
TP5: TTL_RX; TestPoint_Pad_D1.0mm
TP6: TTL_TX_2; TestPoint_Pad_D1.0mm
TP7: TTL_RX_2; TestPoint_Pad_D2.0mm
TP8: SER_B_TXD_OUT; TestPoint_Pad_D2.0mm
TP9: SER_B_RXD_IN; TestPoint_Pad_D1.0mm
TP10: AUD_OUT_L; TestPoint_Pad_D2.0mm
TP11: AUD_OUT_R; TestPoint_Pad_D2.0mm
TP13: PTT_CTRL; TestPoint_Pad_D2.0mm
TP14: USB_GROUND; TestPoint_Pad_D2.0mm
TP15: GROUND; TestPoint_Pad_D2.0mm
TP16: +12V; TestPoint_Pad_D2.0mm
TP17: +2V5; TestPoint_Pad_D2.0mm
TP18: +5V; TestPoint_Pad_D2.0mm
U1: L7805; TO-220-3_Horizontal_TabDown
U2: 24LC04; DIP-8_W7.62mm
U3: APX809_810-xxSA; SOT-23_Handsoldering
U4, U5: AP22814AW5; SOT-23-5
U6: USB2514B-AEZC; QFN-36-1EP_6x6mm_P0.5mm_EP3.7x3.7mm
U7: LM1117-3.3; TO-252-2
U8: TBA 1-0511; Converter_DCDC_Murata_CRE1xxxxxx3C_THT
U9: 4069; TSSOP-14_4.4x5mm_P0.65mm
U10: AP2171W; SOT-23-5
U11, U12: TLP2662; DIP-8_W7.62mm
U13: MAX3232; TSSOP-16_4.4x5mm_P0.65mm
U14: AT93C46D; DIP-8_W7.62mm
U15: PCM2900CDB; SSOP-28_5.3x10.2mm_P0.65mm
U16: 74AHCT1G04; SOT-23-5_HandSoldering
U17: FT2232HL; LQFP-64_10x10mm_P0.5mm
U18, U20, U21: PC817; SMDIP-4_W7.62mm
U19, U22: CRIYCHLEY9000; NORMAL
X1: MAB5SH
Y1: 24MHz; Crystal_SMD_Abracon_ABM8G-4Pin_3.2x2.5mm
Y2, Y3: 12MHz; Crystal_SMD_Abracon_ABM8G-4Pin_3.2x2.5mm

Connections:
+1V8: C25.1, C26.1, C28.1, C35.1, U17.12 (VCORE), U17.37 (VCORE), U17.49 (VREGOUT), U17.64 (VCORE)
+2V5: R13.2, R14.1, TP17.1, U6.27 (VBUS_DET)
+3V3: C4.1, L1.1, L4.1, R3.1, R7.1, R18.2, R19.2, R47.2, R57.1, R59.1, U2.8 (VCC), U7.2 (VO)
+5V: C15.1, C16.1, C17.1, D12.1 (AB), D12.3 (AR), D12.5 (AG), L2.1, L5.1, R23.2, R34.1, TP18.1, U4.1 (OUT), U5.1 (OUT), U7.3 (VI), U10.5 (IN)
+5VP: J7.1 (VBUS1), J7.5 (VBUS2), U10.1 (OUT)
+12V: C1.1, C3.1, D4.1 (K), R16.1, TP16.1, U1.1 (IN)
/5VD12: C8.1, C10.1, C42.1, U1.3 (OUT), U4.4 (EN), U4.5 (IN)
/+5VP_EN: R23.1, U10.4 (EN)
/+5VP_OK: R34.2, TP3.1, U10.3 (~FLG)
/AF_FRM_RADIO_PREINS: J11.T, R69.1, R70.2
/AUD_IN_LEFT: C58.1, U15.12 (VINL)
/AUD_IN_RIGHT: C59.1, U15.13 (VINR)
/AUD_IN_SUM: J11.R, R61.1, R62.2
/AUD_OUT_LEFT: C54.1, C55.2, TP10.1, U15.16 (VOUTL)
/AUD_OUT_RIGHT: C50.1, C57.2, TP11.1, U15.15 (VOUTR)
/AUD_OUT_SUM: C62.2, J12.T
/AUD_USB_DN: R43.2, U15.2 (D-)
/AUD_USB_DP: R42.2, R45.1, U15.1 (D+)
/AUD_VBUS: C37.1, C39.1, C40.1, R53.2, U15.3 (VBUS)
/AUD_VDDI: C27.1, R45.2, U15.8 (SEL0), U15.9 (SEL1), U15.27 (VDDI)
/CAT_UART_RX: J3.1, R56.1, SW1.6 (C), U9.1
/CAT_UART_TX: J3.2, R40.1, SW1.3 (C)
/D+: J2.3 (D+), R12.1
/D-: J2.2 (D-), R11.1
/DCDC_IN: C18.1, C19.1, L2.2, U8.2 (+VIN)
/DCDC_OUT: C20.1, C22.2, L3.1, U8.4 (+VOUT)
/DP1+: J7.3 (D1+), R30.2
/DP1-: J7.2 (D1-), R26.2
/DP2+: J7.7 (D2+), R24.2
/DP2-: J7.6 (D2-), R22.2
/H_AUD_USBD+: R42.1, U6.9 (USBDP_DN4/PRT_DIS_P4)
/H_AUD_USBD-: R43.1, U6.8 (USBDM_DN4/PRT_DIS_M4)
/H_BIAS: R10.2, U6.35 (RBIAS)
/H_DP1+: R30.1, U6.2 (USBDP_DN1/PRT_DIS_P1)
/H_DP1-: R26.1, U6.1 (USBDM_DN1/PRT_DIS_M1)
/H_DP2+: R24.1, U6.4 (USBDP_DN2/PRT_DIS_P2)
/H_DP2-: R22.1, U6.3 (USBDM_DN2/PRT_DIS_M2)
/H_EE_SCL: J5.3, R19.1, U2.6 (SCL)
/H_EE_SDA: J5.1, R18.1, U2.5 (SDA)
/H_HOST_USBD+: R12.2, U6.31 (USBDP_UP)
/H_HOST_USBD-: R11.2, U6.30 (USBDM_UP)
/H_REM0: R1.2, R5.2, U6.28 (SUSP_IND/LOCAL_PWR/NON_REM0)
/H_REM1: J5.2, R6.2, U6.22 (SDA/SMBDATA/NON_REM1)
/H_RST: C7.2, R15.2, U3.2 (~RST), U6.26 (RESET_N)
/H_SEL0: J5.4, R4.2, U6.24 (SCL/SMBCLK/CFG_SEL0)
/H_SEL1: D5.1 (K), D6.2 (A), R7.2, R8.2, U6.25 (HS_IND/CFG_SEL1)
/H_SER_USBD+: R46.1, U6.7 (USBDP_DN3/PRT_DIS_P3)
/H_SER_USBD-: R48.1, U6.6 (USBDM_DN3/PRT_DIS_M3)
/H_VDD: C11.1, C12.1, C13.1, C14.1, L1.2, R15.1, U3.3 (Vcc), U6.5 (VDDA33), U6.10 (VDDA33), U6.15 (VDD33), U6.23 (VDD33), U6.29 (VDDA33), U6.36 (VDDA33)
/H_XTALIN: C2.1, U6.33 (XTALIN/CLKIN), Y1.1
/H_XTALO: C5.1, U6.32 (XTALOUT), Y1.3
/PTT_ACTH: R78.1, SW7.3 (C), U21.3
/PTT_ACTL: SW7.1 (A), U20.4
/PTT_CTRL: D17.1 (K), D18.1 (K), D19.1 (K), D20.1 (K), R41.2, SW3.3 (C), TP13.1, U16.2
/PTT_CTRL_SW: Q4.1 (B), R63.1
/RCA_LEFT: C54.2, C60.2, J10.1 (In)
/RCA_RIGHT: C50.2, C61.2, J9.1 (In)
/RS232RX: J8.2, U13.13 (R1IN)
/RS232TX: J8.3, U13.14 (T1OUT)
/RX_ACT_SEP: R31.2, SW5.5, SW5.6, SW5.7, SW5.8, U18.3
/SER_A_CTS_IN: RN1.5 (R4), SW5.1, U17.19 (ADBUS3)
/SER_A_DSR_IN: RN1.4 (R3), SW5.2, U17.22 (ADBUS5)
/SER_A_DTR_OUT: SW4.2, U17.21 (ADBUS4)
/SER_A_RTS_OUT: SW4.1, U17.18 (ADBUS2)
/SER_B_CTS_IN: RN1.3 (R2), SW5.3, U17.41 (BDBUS3)
/SER_B_DSR_IN: RN1.2 (R1), SW5.4, U17.44 (BDBUS5)
/SER_B_DTR_OUT: SW4.4, U17.43 (BDBUS4)
/SER_B_RTS_OUT: SW4.3, U17.40 (BDBUS2)
/SER_B_RXD_IN: R29.1, SW8.2 (B), TP9.1, U17.39 (BDBUS1)
/SER_B_RXD_RS: SW8.3 (C), U11.6 (VO2)
/SER_B_RXD_TTL: SW8.1 (A), U11.7 (VO1)
/SER_B_RXLED: D16.1 (K), U17.54 (BCBUS3)
/SER_B_TXD_OUT: TP8.1, U12.2 (C1), U12.3 (C2), U17.38 (BDBUS0)
/SER_B_TXLED: D15.1 (K), U17.55 (BCBUS4)
/SER_D+: R46.2, U17.8 (DP)
/SER_D-: R48.2, U17.7 (DM)
/SER_EECS: R52.1, U14.1 (CS), U17.63 (EECS)
/SER_EEDT: R50.1, U14.3 (DI), U17.61 (EEDATA)
/SER_VPLL: C34.1, C36.1, C38.1, L4.2, L6.1, U17.4 (VPHY), U17.9 (VPLL)
/SER_XI: C30.1, U17.2 (OSCI), Y2.3
/SER_XO: C31.1, U17.3 (OSCO), Y2.1
/TTL_RX: R33.2, TP5.1, U13.12 (R1OUT)
/TTL_RX_2: R32.2, TP7.1, U9.4
/TTL_TX: R39.1, TP4.1, U12.6 (VO2), U13.11 (T1IN)
/TTL_TX_2: R38.1, TP6.1, U9.11, U12.7 (VO1)
/YAESU_FILTERED_AUD: J6.5, SW2.1 (A)
/YAESU_FLAT_AUD: J6.4, SW2.3 (C)
/~PTT_CTRL: SW3.1 (A), U16.4
/~SER_RST: R47.1, U17.14 (~RESET)
AF_FRM_RADIO: C64.1, J4.3, SW2.2 (B), X1.4
AF_TO_RADIO: J4.5, J6.1, U19.P$1, X1.1
GND: C1.2, C2.2, C3.2, C4.2, C5.2, C6.1, C7.1, C8.2, C9.1, C10.2, C11.2, C12.2, C13.2, C14.2, C15.2, C16.2, C17.2, C18.2, C25.2, C26.2, C27.2, C28.2, C30.2, C31.2, C34.2, C35.2, C36.2, C37.2, C38.2, C39.2, C40.2, C41.2, C42.2, C43.2, C45.2, C46.2, C47.2, C48.2, C49.2, C51.2, C52.2, C53.2, C56.2, D1.1 (K), J1.2, J2.4 (GND), J2.5 (Shield), J7.4 (GND1), J7.8 (GND2), J7.9 (Shield), J9.2 (Ext), J10.2 (Ext), J11.S, J11.SN, J12.S, J12.SN, Q1.2 (E), Q2.2 (E), Q3.2 (E), Q4.2 (E), R1.1, R2.1, R4.1, R6.1, R8.1, R10.1, R14.2, R20.1, R35.2, R44.1, R54.1, R58.1, R60.1, R70.1, RN1.1 (common), TP14.1, U1.2 (GND), U2.1 (A0), U2.2 (A1), U2.3 (A2), U2.4 (GND), U2.7 (WP), U3.1 (GND), U4.2 (GND), U5.2 (GND), U6.37 (VSS), U7.1 (GND), U8.1 (-VIN), U10.2 (GND), U11.5 (GND), U14.5 (GND), U15.4 (DGNDU), U15.11 (AGNDC), U15.18 (AGNDP), U15.22 (AGNDX), U15.26 (DGND), U16.3 (GND), U17.1 (GND), U17.5 (GND), U17.10 (AGND), U17.11 (GND), U17.13 (TEST), U17.15 (GND), U17.25 (GND), U17.35 (GND), U17.47 (GND), U17.51 (GND), U19.P$4, U22.P$2, Y1.4, Y2.2, Y3.4
GNDREF: C20.2, C21.2, C22.1, C23.2, C32.2, C33.2, J3.3, J4.7, J6.2, J8.0 (PAD), J8.5, R56.2, R78.2, TP15.1, U8.3 (-VOUT), U9.5, U9.7 (VSS), U9.9, U12.5 (GND), U13.15 (GND), U18.2, U19.P$2, U20.3, U22.P$4, X1.2, X1.PE, X1.PE@ (PE)
unnamed: C6.2, U6.34 (PLLFILT)
unnamed: C9.2, U6.14 (CRFILT)
unnamed: C19.2, R20.2
unnamed: C24.1, U13.1 (C1+)
unnamed: C24.2, U13.3 (C1-)
unnamed: C29.1, U13.4 (C2+)
unnamed: C29.2, U13.5 (C2-)
unnamed: C32.1, U13.2 (VS+)
unnamed: C33.1, U13.6 (VS-)
unnamed: C43.1, U15.23 (VCCXI)
unnamed: C45.1, U15.19 (VCCP2I)
unnamed: C46.1, U15.17 (VCCP1I)
unnamed: C48.1, U15.14 (VCOM)
unnamed: C49.1, U15.10 (VCCCI)
unnamed: C51.1, R55.2, U15.21 (XTI), Y3.3
unnamed: C52.1, R55.1, U15.20 (XTO), Y3.1
unnamed: C55.1, R58.2
unnamed: C57.1, R60.2
unnamed: C58.2, R61.2
unnamed: C59.2, R62.1
unnamed: C60.1, R67.1
unnamed: C61.1, R68.1
unnamed: C62.1, R67.2, R68.2
unnamed: C63.1, J12.R
unnamed: C63.2, U19.P$3
unnamed: C64.2, U22.P$3
unnamed: D1.2 (A), R5.1
unnamed: D4.2 (A), J1.1
unnamed: D5.2 (A), R3.2
unnamed: D6.1 (K), R2.2
unnamed: D7.1 (K), R9.1, SW1.2 (B)
unnamed: D12.2 (KB), R37.1
unnamed: D12.4 (KR), R35.1
unnamed: D12.6 (KR), R36.1
unnamed: D15.2 (A), R57.2
unnamed: D16.2 (A), R59.2
unnamed: D17.2 (A), SW4.8
unnamed: D18.2 (A), SW4.7
unnamed: D19.2 (A), SW4.6
unnamed: D20.2 (A), SW4.5
unnamed: J11.RN, J11.TN
unnamed: J12.RN, J12.TN
unnamed: L5.2, R53.1
unnamed: Q1.1 (B), R16.2
unnamed: Q1.3 (C), R17.1, U5.4 (EN)
unnamed: Q2.1 (B), R31.1
unnamed: Q2.3 (C), R37.2
unnamed: Q3.1 (B), R41.1
unnamed: Q3.3 (C), R36.2
unnamed: Q4.3 (C), U20.2, U21.2
unnamed: Q5.1 (B), R81.1, SW6.4 (A)
unnamed: Q5.2 (E), R80.1
unnamed: Q5.3 (C), SW6.1 (A)
unnamed: R27.2, U12.1 (A1)
unnamed: R28.2, U12.4 (A2)
unnamed: R32.1, U11.2 (C1)
unnamed: R33.1, U11.3 (C2)
unnamed: R40.2, U9.12
unnamed: R44.2, U17.6 (REF)
unnamed: R49.1, R50.2, U14.4 (DO)
unnamed: R51.1, U14.2 (SCLK), U17.62 (EECLK)
unnamed: R54.2, U15.24 (DIN)
unnamed: R63.2, SW3.2 (B)
unnamed: R65.1, U20.1
unnamed: R66.1, U21.1
unnamed: R69.2, U22.P$1
unnamed: R79.1, SW6.6 (C)
unnamed: R79.2, SW6.3 (C)
unnamed: SW6.2 (B), U18.1
unnamed: TP1.1, U4.3 (~FLG)
unnamed: TP2.1, U5.3 (~FLG)
unnamed: U9.2, U9.3
unnamed: U9.10, U9.13
PTT: D7.2 (A), J4.4, J6.3, R9.2, SW1.5 (B), SW7.2 (B), X1.3
RX_ACTIVE: J4.1, J6.6, SW6.5 (B), X1.5
VBUS: J2.1 (VBUS), R13.1, R17.2, U5.5 (IN)
VCC: C41.1, C47.1, C53.1, C56.1, L6.2, R27.1, R28.1, R29.2, R49.2, R51.2, R52.2, R65.2, R66.2, U11.8 (VCC), U14.6 (ORG), U14.8 (VCC), U16.5 (VCC), U17.20 (VCCIO), U17.31 (VCCIO), U17.42 (VCCIO), U17.50 (VREGIN), U17.56 (VCCIO), U18.4
VD: C21.1, C23.1, L3.2, R38.2, R39.2, R80.2, R81.2, U9.14 (VDD), U11.1 (A1), U11.4 (A2), U12.8 (VCC), U13.16 (VCC), U21.4

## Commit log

2024-02-17 eagle library
    [radio-usb.kicad_sch]
2024-02-24 schematic ready
    [radio-usb.kicad_sch]
2024-02-25 routing usb differential pairs
    [radio-usb.kicad_pcb, radio-usb.kicad_sch]
2024-02-26 routing serial ftdi controller
    [radio-usb.kicad_pcb, radio-usb.kicad_sch]
2024-02-28 everything but audio codec
    [radio-usb.kicad_pcb, radio-usb.kicad_sch]
2024-02-29 some components around audio codec
    [radio-usb.kicad_pcb, radio-usb.kicad_sch]
2024-03-03 all components placed
    [radio-usb.kicad_pcb, radio-usb.kicad_sch]
2024-03-03 schematic export
2024-03-04 some pcb routing around io
    [radio-usb.kicad_pcb]
2024-03-05 more pcb traces routing
    [radio-usb.kicad_pcb, radio-usb.kicad_sch]
2024-03-06 almost everything routed
    [radio-usb.kicad_pcb]
2024-03-06 everything but ground poluygon and fixed bourns trafo pinout
    [radio-usb.kicad_pcb, radio-usb.kicad_sch]
2024-03-07 everything routed, bourns audio transformer footprint correcred, ground polygons
    [radio-usb.kicad_pcb, radio-usb.kicad_sch]
2024-03-08 silkscreen description and test points
    [radio-usb.kicad_pcb, radio-usb.kicad_sch]
2024-03-10 fixed mini din 6 orientation, fix via size problems
    [radio-usb.dxf, radio-usb.kicad_pcb, radio-usb.kicad_sch]
2024-03-10 gerber files and another fabrication output
    [bill_of_material_radio-usb.csv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]
2024-03-12 updated bom and exported schematic, corrected some component values
    [bill_of_material_radio-usb.csv, radio-usb.dxf, radio-usb.kicad_sch]
2024-03-21 gerber exports and another files sent to PCBway for production
    [T-V11W169294A-1sets-smd_bom(2024-03-13).xls, T-V11W169294A-1sets-smd_bom(2024-03-14).xls, T-V11W169294A-1sets-smd_bom(2024-03-14)_answer.xls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]
2024-04-06 fix with Y1 part number, cleanup in output files
    [T-V11W169294A-1sets-smd_bom(2024-03-13).xls, T-V11W169294A-1sets-smd_bom(2024-03-14).xls, T-V11W169294A-1sets-smd_bom(2024-03-14)_answer.xls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]
2024-06-21 more cleanup
    [radio-usb.kicad_sch]
2024-06-25 hardware revision b schematic
    [T-V11W169294A-1sets-smd_bom(2024-03-13).xls, T-V11W169294A-1sets-smd_bom(2024-03-14).xls, T-V11W169294A-1sets-smd_bom(2024-03-14)_answer.xls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]
2024-07-02 hw revision b done
    [radio-usb.kicad_pcb, radio-usb.kicad_sch]
2024-08-04 hardware revision b build
    [radio-usb-B_Cu.gbr, radio-usb-B_Mask.gbr, radio-usb-B_Paste.gbr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]
2024-08-19 final production files
    [bom.xls]
2025-03-05 exported schematic
    [radio-usb.kicad_sch]
